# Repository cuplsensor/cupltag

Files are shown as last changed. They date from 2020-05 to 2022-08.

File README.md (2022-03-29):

# cuplTag
The project comprises hardware and firmware. 

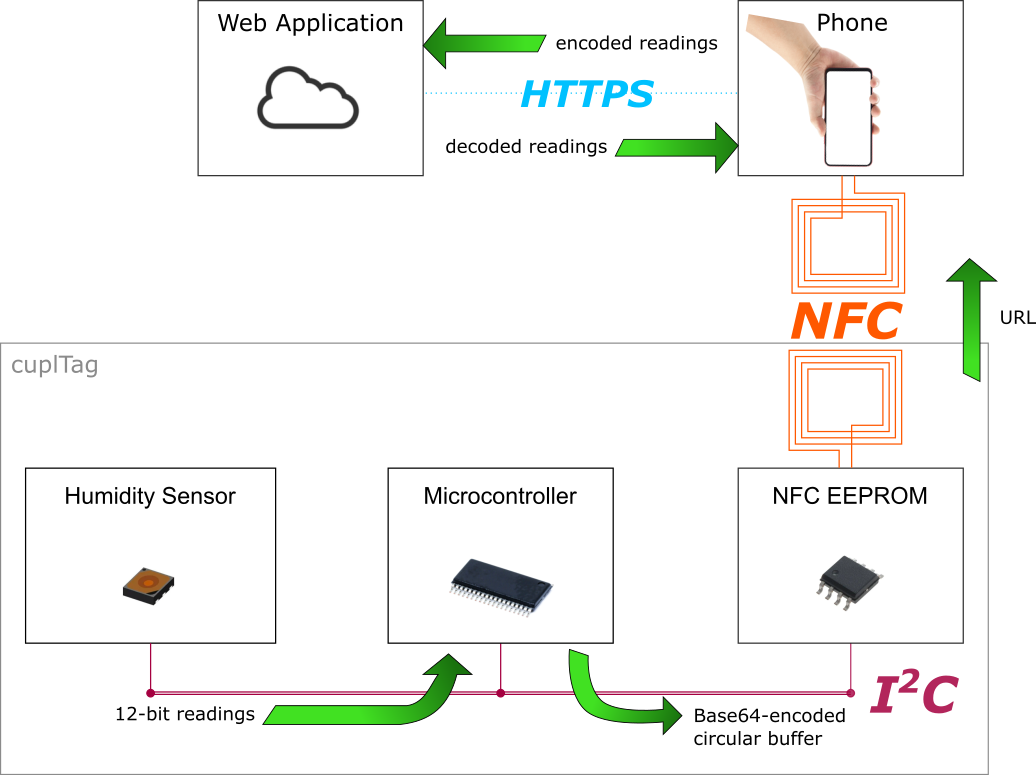
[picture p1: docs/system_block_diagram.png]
System block diagram


The firmware runs on a low power MSP430 microcontroller. It periodically reads temperature and humidity from an [HDC2022](https://www.ti.com/product/HDC2022) sensor. Readings are base-64 encoded and stored in a URL, which resides on an NFC EEPROM. 

When a phone is hovered over a cuplTag, the URL is read and a web browser opens ([demo](https://www.youtube.com/watch?v=ySxt_svazHo)). No app is required. The web application decodes, timestamps and displays readings to the user. 

## Key Features
- Average current consumption ~0.5uA. Runs for years on a CR1220 battery.
- Ease of use. No app to install on the Android / Apple phone.
- Data are automatically uploaded to the web.

[Buy one on Crowd Supply!](https://crowdsupply.com/cupl/cupltag)

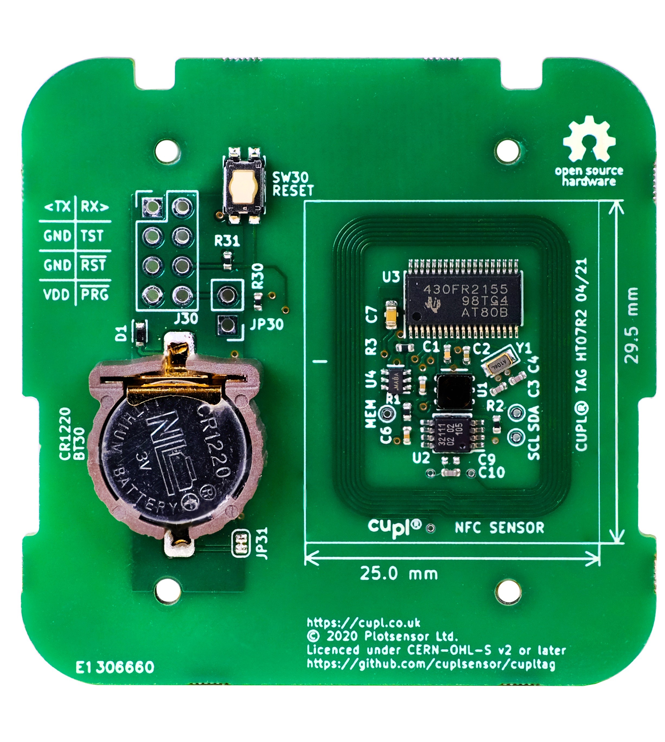
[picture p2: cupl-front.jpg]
Board photo


## Pinout

J30 is a 2.54mm pitch 2x4 way header.

| Pin | Name | Direction | Description | Note |
|-----|---|---|---|---|
| 1 | TX | Output | UART transmit | Transmit from MSP430 |
| 2 | RX | Input | UART receive | Receive to MSP430 |
| 3 | GND  | | GND | |
| 4 | TST  | Input | Spy-Bi-Wire Clock | Also TEST signal for BSL entry |
| 5 | GND  | | GND | |
| 6 | nRST | I/O | Spy-Bi-Wire Data  | Also active low RESET signal |
| 7 | VDD  | Input | Power in | +3V3 |
| 8 | nPRG | Input | Prog. Mode Enable | Active low |

## User Documentation 

### Guides

* [Getting Started](docs/firmware/gettingstarted.rst) by loading the project into Code Composer.
* [Programming](docs/firmware/programming/index.rst) the MSP430.
* [Configuration with UART (1 of 2)](docs/guides/configUARTpt1/index.md).
* [Configuration with UART (2 of 2)](https://github.com/cuplsensor/cuplfrontend/blob/master/docs/guides/configUARTpt2/index.md) [cuplfrontend].
* [Configuration with NFC](docs/guides/configNFC/index.md).

### Interface

* [Configuration Strings](docs/specs/configstrings.rst)  that can be written over the serial port or NFC.

## Code Documentation

[ReadTheDocs](https://cupl.readthedocs.io/projects/tag/en/latest/)

## Licence

### Firmware



### Hardware

[CERN Open Hardware Licence Version 2 - Strongly Reciprocal](https://ohwr.org/cern_ohl_s_v2.txt)

### Documentation



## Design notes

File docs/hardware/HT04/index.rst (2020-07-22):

HT04 Module
-------------

.. _HT04Pinout:

Pinout
*******

Diagram showing pinout of the HT04 module.

+-----+------+-----------+-------------------------+---------------------------------------+
| Pin | Name | Direction | Description             | Note                                  |
+=====+======+===========+=========================+=======================================+
| 1   | TX   | Output    | UART transmit           |                                       |
+-----+------+-----------+-------------------------+---------------------------------------+
| 2   | RX   | Input     | UART receive            | Also ADC input A6                     |
+-----+------+-----------+-------------------------+---------------------------------------+
| 3   | nPRG | Input     | Select programming mode | Active low                            |
+-----+------+-----------+-------------------------+---------------------------------------+
| 4   | TCK  | Input     | Spy-Bi-Wire Clock       | Also TEST signal for BSL entry        |
+-----+------+-----------+-------------------------+---------------------------------------+
| 5   | TDIO | I/O       | Spy-Bi-Wire Data        | Also nRESET signal                    |
+-----+------+-----------+-------------------------+---------------------------------------+
| 6   | GND  |           | GND                     |                                       |
+-----+------+-----------+-------------------------+---------------------------------------+
| 7   | VDD  | Input     | Power in                |                                       |
+-----+------+-----------+-------------------------+---------------------------------------+
| 8   | NC   |           | Not connected           |                                       |
+-----+------+-----------+-------------------------+---------------------------------------+
| 9   | SCL  | Output    | I2C clock               | Pulled-up to VMEM                     |
+-----+------+-----------+-------------------------+---------------------------------------+
| 10  | SDA  | Output    | I2C data                | Pulled-up to VMEM                     |
+-----+------+-----------+-------------------------+---------------------------------------+

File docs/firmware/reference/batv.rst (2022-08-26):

Battery Voltage 
~~~~~~~~~~~~~~~~~

.. doxygenfile:: batv.c

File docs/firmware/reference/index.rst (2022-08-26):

Reference
----------

.. toctree::
   :maxdepth: 2

   main
   hdc2021
   nt3h
   i2c
   stat
   confignfc
   comms_uart
   nvparams
   batv

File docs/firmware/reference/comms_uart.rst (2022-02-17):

Comms UART
~~~~~~~~~~~~

.. doxygenfile:: comms_uart.h

.. doxygenfile:: comms_uart.c

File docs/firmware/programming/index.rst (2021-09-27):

.. _Programming:

Programming
~~~~~~~~~~~~~

These instructions demonstrate how to program and debug the MSP430 on cuplTag.

Equipment
+++++++++++

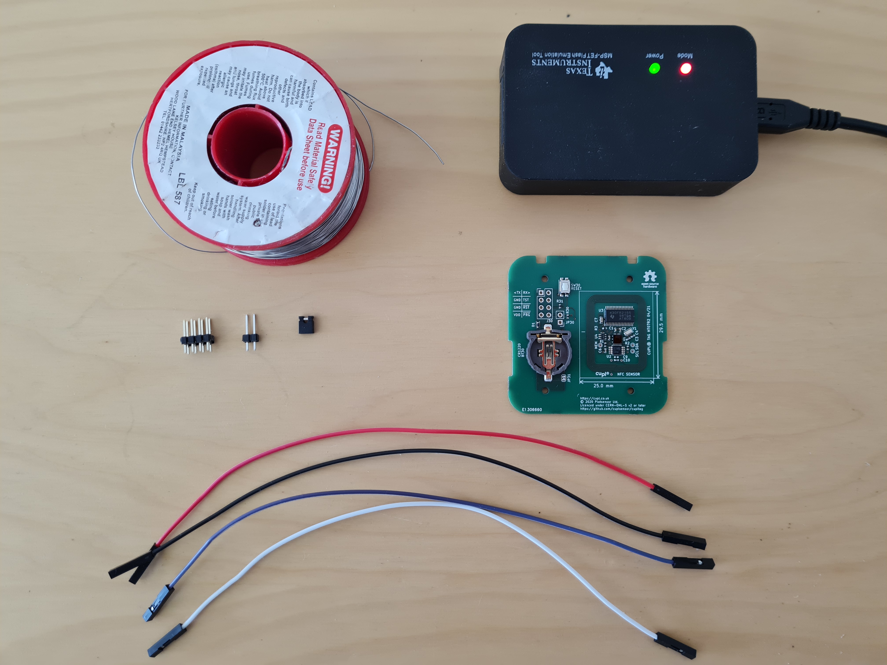
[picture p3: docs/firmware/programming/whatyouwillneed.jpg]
Items needed to program the MSP430


You will need: 

* An MSP-FET with a USB cable.
* A PC running Code Composer Studio.
* 4 coloured jumper wires.
* A 2x4 way 2.54mm pitch pin header.
* A 1x2 way 2.54mm pitch pin header.
* A 2 way jumper.
* Solder.
* A cuplTag PCBA (HT07), unscrewed from the enclosure, with no battery inserted.

Populate the Headers
+++++++++++++++++++++

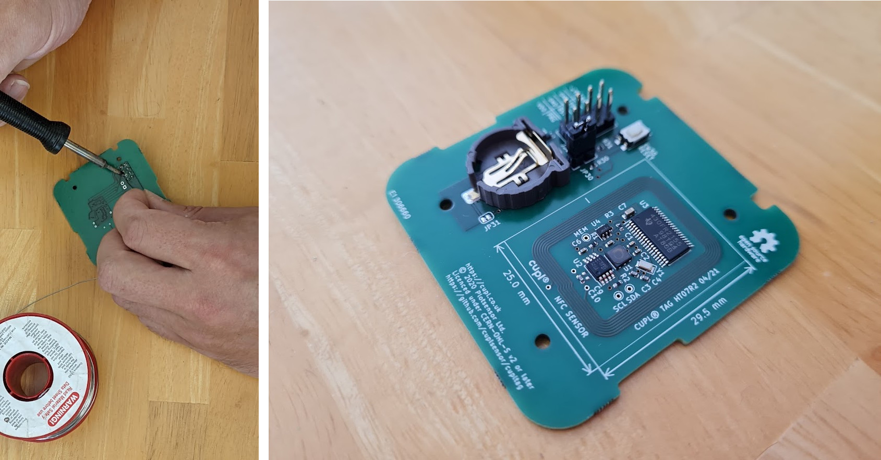
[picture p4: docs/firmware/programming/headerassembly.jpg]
Soldering headers onto HT07


First, solder the pin headers onto J30 and JP30 of HT07. Use the jumper to short JP30. 

Make Connections
+++++++++++++++++

In the diagram below we will make connection J2 instead of J1, because the HT07 has no battery inserted.

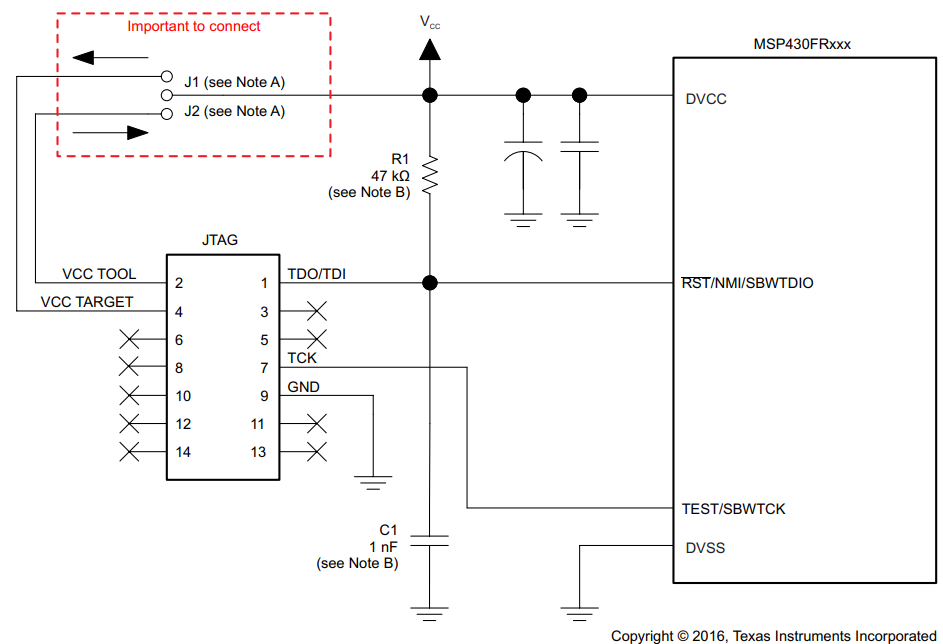
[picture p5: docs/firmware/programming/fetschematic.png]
MSP-FET Spy-Bi-Wire Schematic


Spy-Bi-Wire is used to progra . Connect it to the MSP-FET.

+---------+--------+--------------+-------------+--------------+-----------------+
| Name    | Colour | MSP-FET name | MSP-FET pin | HT07 J30 pin | HT07 J30 name   |
+---------+--------+--------------+-------------+--------------+-----------------+
| +3V3    | Red    | VCC_TOOL     | 2           | 7            | VDD             |
+---------+--------+--------------+-------------+--------------+-----------------+
| GND     | Black  | GND          | 9           | 3            | GND             |
+---------+--------+--------------+-------------+--------------+-----------------+
| SBWTDIO | White  | TDO/TDI      | 1           | 6            | nRST            |
+---------+--------+--------------+-------------+--------------+-----------------+
| SBWTCK  | Purple | TCK          | 7           | 4            | TST             |
+---------+--------+--------------+-------------+--------------+-----------------+

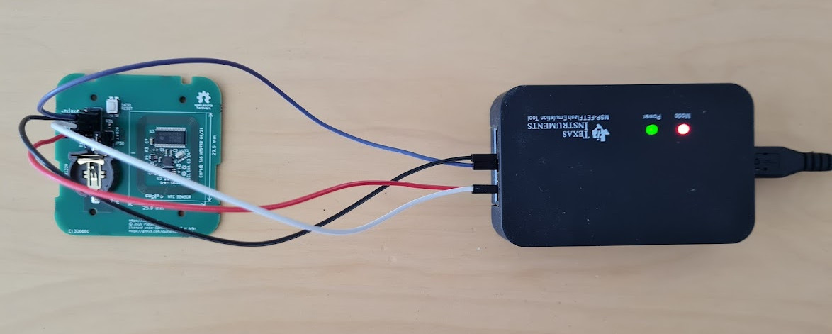
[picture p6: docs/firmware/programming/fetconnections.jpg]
Jumper wire connections on the MSP-FET


Program in CCS
+++++++++++++++++

#. Connect the MSP-FET to a PC with a USB cable. 
#. Open the Code Composer Studio cuplTag project `created earlier <GettingStarted>`.
#. Click on the Debug button. Wait for programming to complete.

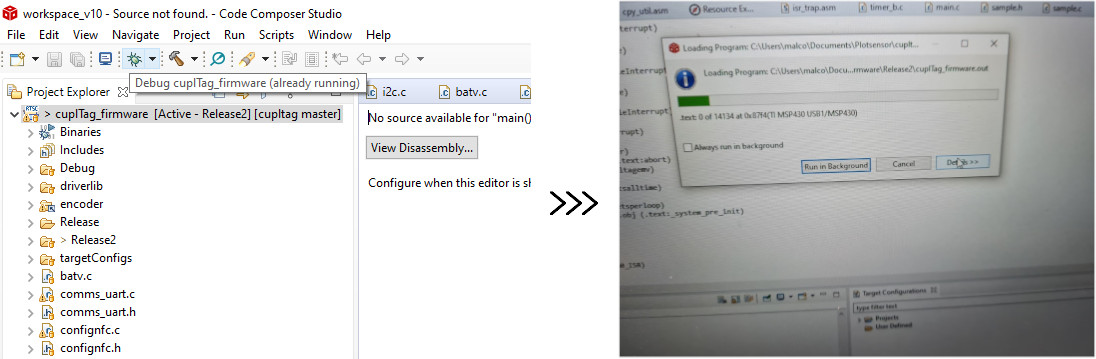
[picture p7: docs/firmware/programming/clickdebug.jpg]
Debug button in Code Composer Studio


Test
+++++

Test the program has loaded correctly by scanning HT07 with your phone. 

If JP30 is shorted, the MSP430 will boot into *programming mode*: The serial port is enabled and a status string is written to an NDEF text record on the tag.

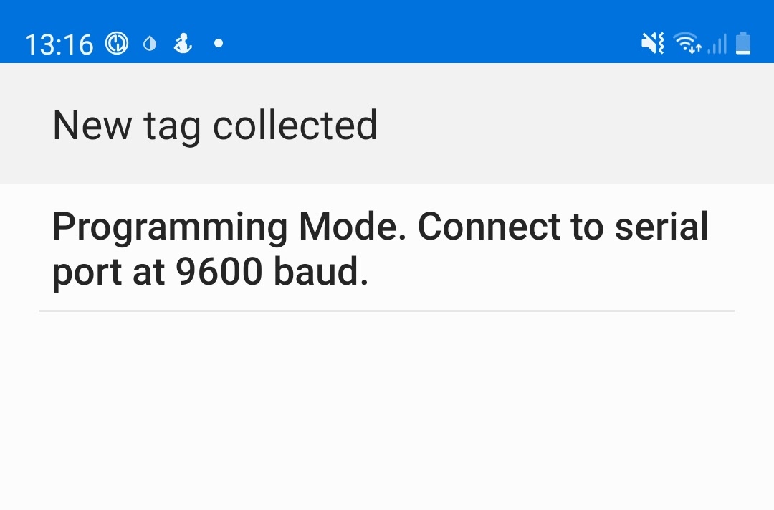
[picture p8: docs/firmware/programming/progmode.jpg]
Programming mode NDEF text record.


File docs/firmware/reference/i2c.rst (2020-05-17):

I2C
~~~~~~

.. doxygenfile:: i2c.h

.. doxygenfile:: i2c.c

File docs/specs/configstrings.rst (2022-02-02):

Configuration Strings
~~~~~~~~~~~~~~~~~~~~~~~

Base URL
*********

+------------------+------------------------------+
| Command ID       | b                            |
+------------------+------------------------------+
| Parameter Length | up to 64                     |
+------------------+------------------------------+
| Parameter value  | Any URL-safe string          |
+------------------+------------------------------+

Example 1: ``<b:localhost:5000>``

Example 2: ``<b:latest.f.cupl.uk>``

This URL will be opened by a phone that taps cuplTag. It should point to a `web application`_ that decodes the `cupl URL parameters`_. 

The scheme (e.g. HTTPS) must not be included.

The domain (e.g. latest.f.cupl.uk) is required. 

The port (e.g. 5000) is only required if it differs from 443 for HTTPS or 80 for HTTP.  

.. _web application: https://github.com/cuplsensor/cuplfrontend

.. _cupl URL parameters: https://cupl.readthedocs.io/projects/codec/en/latest/docs/specification/features.html#url-parameters

Serial
********

+------------------+---------------------+
| Command ID       | w                   |
+------------------+---------------------+
| Parameter Length | 8                   |
+------------------+---------------------+
| Parameter value  | Any URL-safe Base64 |
+------------------+---------------------+

Example: ``<w:KEG2lARW>``

Each cuplTag in a deployment must be uniquely identified by an 8 character serial string. This is written into a `dedicated URL parameter`_ on startup. 

The serial string is normally generated by the web application, when a new tag is defined. It can later be used to view data captured 
from a tag (e.g. https://latest.f.cupl.uk/tag/KEG2lARW).

.. _dedicated URL parameter: https://cupl.readthedocs.io/projects/codec/en/latest/docs/specification/features.html#CODEC_FEAT_38

HMAC Secret Key
*****************

+------------------+---------------------+
| Command ID       | s                   |
+------------------+---------------------+
| Parameter Length | 16                  |
+------------------+---------------------+
| Parameter value  | Any URL-safe Base64 |
+------------------+---------------------+

Example: ``<s:4EOBdBWTsjeFZTm3>``

The secret key is used to generate a `Hash-based Message Authentication Code`_, which is updated whenever a new sample is added to the URL. 

It must be randomly generated and unique to each cuplTag in a deployment. It is feasible for one tag (and the key therein) to be comprimised. 

The secret key will normally be generated by the web application, when a new tag is defined. It is shared between the application and the tag only. 

No data read from a tag will be stored by the web application without HMAC verification; the HMAC computed from the secret key must match that read from cuplTag.

.. _Hash-based Message Authentication Code: https://cupl.readthedocs.io/projects/codec/en/latest/docs/specification/features.html#CODEC_FEAT_24

Sample Interval in Minutes
****************************

+------------------+---------------------+
| Command ID       | t                   |
+------------------+---------------------+
| Parameter Length | 5 (max)             |
+------------------+---------------------+
| Parameter value  | Integer (16-bit)    |
+------------------+---------------------+

Example: ``<t:20>`` for a 20 minute interval.

This sets the time interval between samples in minutes. The minimum interval supported by the web application is 3 minutes. The maximum is 65535 minutes (6 weeks).

The time interval is base64 encoded and written into a `URL parameter` on startup. The web application uses this to timestamp all samples stored on the tag.

.. _URL parameter: https://cupl.readthedocs.io/projects/codec/en/latest/docs/specification/features.html#CODEC_FEAT_10

Disable HTTPS
**************

+------------------+---------------------------------------+
| Command ID       | h                                     |
+------------------+---------------------------------------+
| Parameter Length | 1                                     |
+------------------+---------------------------------------+
| Parameter value  | 0 (HTTPS), 1 (HTTP)                   |
+------------------+---------------------------------------+

Example: ``<h:1>`` to use HTTP (insecure) instead of HTTPS.

Disables HTTPS in the web application URL. This can be helpful during development, because there is no need to obtain an SSL certificate. Not encouraged for production. 

HTTPS and HTTP are the only 2 schemes supported by cuplTag for now.

Use HMAC
************

+------------------+---------------------------------------+
| Command ID       | i                                     |
+------------------+---------------------------------------+
| Parameter Length | 1                                     |
+------------------+---------------------------------------+
| Parameter value  | 0 (HMAC disabled), 1 (HMAC enabled)   |
+------------------+---------------------------------------+

Example ``<i:1>`` to use HMAC-MD5.

When HMAC is disabled, an MD5 checksum is calculated in its place. This means that the secret key is ignored and a decode will be successful providing that the checksums match. 

The feature was used during development, but it is not advised for production. MD5 may suffice for stateless web applications that do not store data from the tag. Standalone MD5 is deprecated as a checksum algorithm.

Minimum Battery Voltage (mV)
*****************************

+------------------+---------------------+
| Command ID       | u                   |
+------------------+---------------------+
| Parameter Length | 4                   |
+------------------+---------------------+
| Parameter value  | Integer (16-bit)    |
+------------------+---------------------+

Example: ``<u:2200>``

Sets the voltage below which the cuplTag does not operate.

Sample Format
**************

+------------------+----------------------------------------------+
| Command ID       | f                                            |
+------------------+----------------------------------------------+
| Parameter Length | 1                                            |
+------------------+----------------------------------------------+
| Parameter value  | 1 (Temperature + RH), 2 (Temperature only)   |
+------------------+----------------------------------------------+

Example 1: ``<f:1>`` for each sample to contain a temperature and relative humidity reading.

Example 2: ``<f:2>`` for each sample to contain a temperature reading only. This doubles the sample capacity.

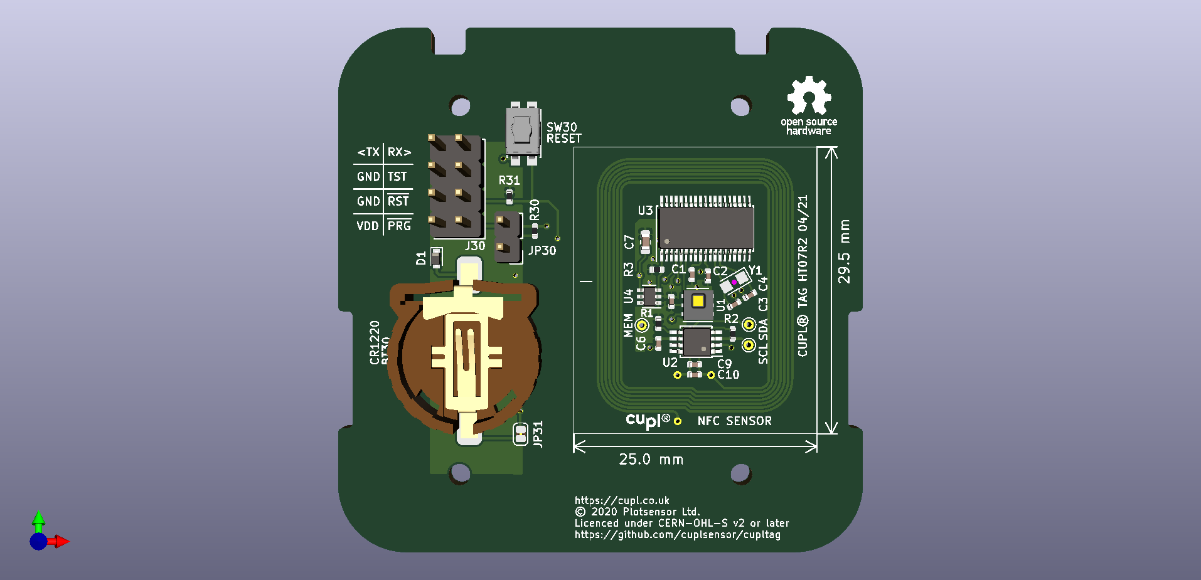
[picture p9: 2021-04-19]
hardware/HT07/HT07.png

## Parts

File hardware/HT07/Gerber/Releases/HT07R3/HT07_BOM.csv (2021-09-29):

Source: | C:\Users\malco\Documents\Plotsensor\cupltag\hardware\HT07\HT07.sch
Date: | 29/09/2021 13:37:43
Tool: | Eeschema (5.1.5)-3
Generator: | C:\Program Files\KiCad\bin\scripting\plugins/bom_csv_grouped_by_value.py
Component Count: | 32
Individual Components:
Item | Qty | Reference(s) | Value | LibPart | Footprint | Datasheet | ALT | COST@100 | FIT | MANF | MANF# | SUPPLIER | SUPPLIER#
 |  | AE1 | Antenna_Loop | device:Antenna_Loop | CUPL_FP:Class_6_NXP_7loop_150u | ~ |  |  | NF
 |  | BT30 | CR1220 | device:Battery_Cell | CUPL_FP:MPD_BC501SM_CR1220 | ~ |  |  |  | MPD | BC501SM | DIGIKEY | BC501SM-TRCT-ND
 |  | C1 | 1N | device:C | CUPL_FP:C_0402_1005Metric
 |  | C2 | 100N | device:C | CUPL_FP:C_0402_1005Metric |  |  |  |  | YAGEO | CC0402KRX7R7BB104 | FARNELL | 9402047
 |  | C3 | 22P | device:C | CUPL_FP:C_0402_1005Metric |  |  |  |  | AVX | 04025A220JAT2A | FARNELL | 1327634
 |  | C4 | 22P | device:C | CUPL_FP:C_0402_1005Metric |  |  |  |  | AVX | 04025A220JAT2A | FARNELL | 1327634
 |  | C6 | 100N | device:C | CUPL_FP:C_0402_1005Metric |  |  |  |  | YAGEO | CC0402KRX7R7BB104 | FARNELL | 9402047
 |  | C7 | 10U | device:C | CUPL_FP:C_0603_1608Metric |  |  | £0.115 |  | AVX | 06036D106MAT2A | FARNELL | 1833804
 |  | C8 | 100N | device:C | CUPL_FP:C_0402_1005Metric |  |  |  |  | YAGEO | CC0402KRX7R7BB104 | FARNELL | 9402047
 |  | C9 | 0P | device:C | CUPL_FP:C_0402_1005Metric |  |  |  | NF | AVX |  | FARNELL
 |  | C10 | 18P | device:C | CUPL_FP:C_0402_1005Metric |  |  |  |  | MURATA | 04025A180FAT2A | FARNELL | 2332495
 |  | D1 | D_Schottky | device:D_Schottky | CUPL_FP:D_SOD-523 | ~ |  |  |  | ROHM | RB520SM-40FHT2R | MOUSER | 755-RB520SM-40FHT2R
 |  | J30 | Conn_02x04_Odd_Even | Connector_Generic:Conn_02x04_Odd_Even | CUPL_FP:PinHeader_2x04_P2.54mm_Vertical | ~ |  |  | NF
 |  | JP30 | Jumper_2_Open | Jumper:Jumper_2_Open | CUPL_FP:PinHeader_1x02_P2.54mm_Vertical | ~ |  |  | NF
 |  | JP31 | SolderJumper_2_Bridged_small | Jumper:SolderJumper_2_Bridged | CUPL_FP:SolderJumper-2_Bridged_small | ~ |  |  | NF
 |  | LOGO1 | Logo_Open_Hardware_Small | Graphic:Logo_Open_Hardware_Small | CUPL_FP:OSHW-Logo_5.7x6mm_SilkScreen | ~
 |  | LOGO2 | CUPL | CUPL:CUPL | CUPL_FP:logo |  |  |  | NF
 |  | P1 | Conn_01x01_MountingPin | Mechanical:MountingHole | CUPL_FP:MountingHole_2.2mm_M2 | ~ |  |  | NF
 |  | P2 | Conn_01x01_MountingPin | Mechanical:MountingHole | CUPL_FP:MountingHole_2.2mm_M2 | ~ |  |  | NF
 |  | P3 | Conn_01x01_MountingPin | Mechanical:MountingHole | CUPL_FP:MountingHole_2.2mm_M2 | ~ |  |  | NF
 |  | P4 | Conn_01x01_MountingPin | Mechanical:MountingHole | CUPL_FP:MountingHole_2.2mm_M2 | ~ |  |  | NF
 |  | R1 | 10K | device:R | CUPL_FP:R_0402_1005Metric |  |  |  |  | VISHAY | CRCW040210K0FKED | FARNELL | 1469669
 |  | R2 | 10K | device:R | CUPL_FP:R_0402_1005Metric |  |  |  |  | VISHAY | CRCW040210K0FKED | FARNELL | 1469669
 |  | R3 | 100K | device:R | CUPL_FP:R_0402_1005Metric |  |  |  |  | BOURNS | CR0402-FX-1003GLF | MOUSER | 652-CR0402FX-1003GLF
 |  | R30 | 47K | device:R | CUPL_FP:R_0402_1005Metric |  |  |  |  | PANASONIC | ERJ2RKF4702X | FARNELL | 2302806
 |  | R31 | 47K | device:R | CUPL_FP:R_0402_1005Metric |  |  |  |  | PANASONIC | ERJ2RKF4702X | FARNELL | 2302806
 |  | SW30 | SW_Push | Switch:SW_Push | CUPL_FP:SW_SPST_EVQP2 | ~ |  |  |  | PANASONIC | EVQP2402W | FARNELL | 2860944
 |  | U1 | HDC2022DEPR | CUPL:HDC2021 | CUPL_FP:HDC2021 | https://www.ti.com/lit/ds/symlink/hdc2021.pdf |  |  |  | TEXAS | HDC2022DEPR | TEXAS | HDC2022DEPR
 |  | U2 | NT3H2111W0FTTJ | CUPL:NT3H2111 | CUPL_FP:TSSOP-8_3x3mm_P0.65mm | https://www.nxp.com/docs/en/data-sheet/NT3H2111_2211.pdf | ALT: NT3H2211W0FTTJ |  |  | NXP | NT3H2111W0FTTJ | FARNELL | 2663150
 |  | U3 | MSP430FR2155TDBT | CUPL:MSP430FR2155TDBT | CUPL_FP:TSSOP-38_4.4x9.7mm_P0.5mm | http://www.ti.com/lit/ds/symlink/msp430fr2155.pdf | ALT: MSP430FR2355TDBTR |  |  | TEXAS | MSP430FR2155TDBT | MOUSER | 595-MSP430FR2155TDBTR
 |  | U4 | SIP32431DR3-T1GE3 | CUPL:SIP32431DR3-T1GE3 | CUPL_FP:SOT-363_SC-70-6 | http://www.farnell.com/datasheets/2049671.pdf |  |  |  | VISHAY | SIP32431DR3-T1GE3 | FARNELL | 2361509
 |  | Y1 | 32K768 | CUPL:XTAL_32768HZ_3215 | CUPL_FP:Crystal_SMD_2012-2Pin_2.0x1.2mm_HandSoldering | http://www.farnell.com/datasheets/1912628.pdf |  | £0.36530 |  | EPSON | FC-12M 32.7680KD-A3 | DIGIKEY | SER3673CT-ND
Collated Components:
Item | Qty | Reference(s) | Value | LibPart | Footprint | Datasheet | ALT | COST@100 | FIT | MANF | MANF# | SUPPLIER | SUPPLIER#
1 | 1 | AE1 | Antenna_Loop | device:Antenna_Loop | CUPL_FP:Class_6_NXP_7loop_150u | ~ |  |  | NF
2 | 1 | BT30 | CR1220 | device:Battery_Cell | CUPL_FP:MPD_BC501SM_CR1220 | ~ |  |  |  | MPD | BC501SM | DIGIKEY | BC501SM-TRCT-ND
3 | 1 | C1 | 1N | device:C | CUPL_FP:C_0402_1005Metric
4 | 3 | C2, C6, C8 | 100N | device:C | CUPL_FP:C_0402_1005Metric |  |  |  |  | YAGEO | CC0402KRX7R7BB104 | FARNELL | 9402047
5 | 2 | C3, C4 | 22P | device:C | CUPL_FP:C_0402_1005Metric |  |  |  |  | AVX | 04025A220JAT2A | FARNELL | 1327634
6 | 1 | C7 | 10U | device:C | CUPL_FP:C_0603_1608Metric |  |  | £0.115 |  | AVX | 06036D106MAT2A | FARNELL | 1833804
7 | 1 | C9 | 0P | device:C | CUPL_FP:C_0402_1005Metric |  |  |  | NF | AVX |  | FARNELL
8 | 1 | C10 | 18P | device:C | CUPL_FP:C_0402_1005Metric |  |  |  |  | MURATA | 04025A180FAT2A | FARNELL | 2332495
9 | 1 | D1 | D_Schottky | device:D_Schottky | CUPL_FP:D_SOD-523 | ~ |  |  |  | ROHM | RB520SM-40FHT2R | MOUSER | 755-RB520SM-40FHT2R
10 | 1 | J30 | Conn_02x04_Odd_Even | Connector_Generic:Conn_02x04_Odd_Even | CUPL_FP:PinHeader_2x04_P2.54mm_Vertical | ~ |  |  | NF
11 | 1 | JP30 | Jumper_2_Open | Jumper:Jumper_2_Open | CUPL_FP:PinHeader_1x02_P2.54mm_Vertical | ~ |  |  | NF
12 | 1 | JP31 | SolderJumper_2_Bridged_small | Jumper:SolderJumper_2_Bridged | CUPL_FP:SolderJumper-2_Bridged_small | ~ |  |  | NF
13 | 1 | LOGO1 | Logo_Open_Hardware_Small | Graphic:Logo_Open_Hardware_Small | CUPL_FP:OSHW-Logo_5.7x6mm_SilkScreen | ~
14 | 1 | LOGO2 | CUPL | CUPL:CUPL | CUPL_FP:logo |  |  |  | NF
15 | 4 | P1, P2, P3, P4 | Conn_01x01_MountingPin | Mechanical:MountingHole | CUPL_FP:MountingHole_2.2mm_M2 | ~ |  |  | NF
16 | 2 | R1, R2 | 10K | device:R | CUPL_FP:R_0402_1005Metric |  |  |  |  | VISHAY | CRCW040210K0FKED | FARNELL | 1469669
17 | 1 | R3 | 100K | device:R | CUPL_FP:R_0402_1005Metric |  |  |  |  | BOURNS | CR0402-FX-1003GLF | MOUSER | 652-CR0402FX-1003GLF
18 | 2 | R30, R31 | 47K | device:R | CUPL_FP:R_0402_1005Metric |  |  |  |  | PANASONIC | ERJ2RKF4702X | FARNELL | 2302806
19 | 1 | SW30 | SW_Push | Switch:SW_Push | CUPL_FP:SW_SPST_EVQP2 | ~ |  |  |  | PANASONIC | EVQP2402W | FARNELL | 2860944
20 | 1 | U1 | HDC2022DEPR | CUPL:HDC2021 | CUPL_FP:HDC2021 | https://www.ti.com/lit/ds/symlink/hdc2021.pdf |  |  |  | TEXAS | HDC2022DEPR | TEXAS | HDC2022DEPR
21 | 1 | U2 | NT3H2111W0FTTJ | CUPL:NT3H2111 | CUPL_FP:TSSOP-8_3x3mm_P0.65mm | https://www.nxp.com/docs/en/data-sheet/NT3H2111_2211.pdf | ALT: NT3H2211W0FTTJ |  |  | NXP | NT3H2111W0FTTJ | FARNELL | 2663150
22 | 1 | U3 | MSP430FR2155TDBT | CUPL:MSP430FR2155TDBT | CUPL_FP:TSSOP-38_4.4x9.7mm_P0.5mm | http://www.ti.com/lit/ds/symlink/msp430fr2155.pdf | ALT: MSP430FR2355TDBTR |  |  | TEXAS | MSP430FR2155TDBT | MOUSER | 595-MSP430FR2155TDBTR
23 | 1 | U4 | SIP32431DR3-T1GE3 | CUPL:SIP32431DR3-T1GE3 | CUPL_FP:SOT-363_SC-70-6 | http://www.farnell.com/datasheets/2049671.pdf |  |  |  | VISHAY | SIP32431DR3-T1GE3 | FARNELL | 2361509
24 | 1 | Y1 | 32K768 | CUPL:XTAL_32768HZ_3215 | CUPL_FP:Crystal_SMD_2012-2Pin_2.0x1.2mm_HandSoldering | http://www.farnell.com/datasheets/1912628.pdf |  | £0.36530 |  | EPSON | FC-12M 32.7680KD-A3 | DIGIKEY | SER3673CT-ND

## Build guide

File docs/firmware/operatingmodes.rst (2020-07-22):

Operating Modes
-----------------

.. _NormalMode:

Primary
~~~~~~~~

The software progresses into the loop at the bottom of the :ref:`StateChart`:

* Programming mode is not entered because the nPRG pin is deasserted.
* Tag configuration is present according to :cpp:func:`init_configcheck`.
* No evidence of repeated resets has been found by :cpp:func:`init_errorcheck`.

In normal operation the tag is updated periodically with calls to cuplCodec. To conserve power the
MSP430 Real Time Clock (RTC) is set to generate interrupts at one minute intervals. The RTC
is clocked by the 32.768 kHz watch crystal. A majority of time is spent
waiting in standby (LPM3) for the next RTC interrupt. The VMEM domain that includes the NT3H2211 NFC tag
and the HDC2021 is powered off during this time.
Therefore cuplTag draws little more than 1.43uA; equal to the MSP430 consumption in LPM3 (`MSP430Datasheet`_).

Every Minute
*************

#. cuplTag wakes up from standby (LPM3).
#. Minute counter is incremented.
#. The VMEM domain is powered on.
#. A call is made to :cpp:func:`confignfc_check`. This checks if an NDEF text record
   (assumed to contain configuration data) is present on the tag. If so, a reset occurs.
#. A call is made to :cpp:func:`enc_setelapsed` in cuplCodec. The minuteselapsed field (CODEC_FEAT_26) of the cuplCodec URL
   is updated.
#. The VMEM domain is powered off.
#. cuplTag returns to LPM3.

At the Sample Interval (in minutes)
**************************************

#. cuplTag wakes up from standby (LPM3).
#. Minute counter is reset to 0.
#. The VMEM domain is powered on.
#. A call is made to :cpp:func:`confignfc_check`. This checks if an NDEF text record
   (assumed to contain configuration data) is present on the tag. If so, a reset occurs.
#. A sample is requested from the humidity sensor with :cpp:func:`hdc2010_startconv`.
#. The MSP430 waits in LPM3 until the DRDY line of this sensor is asserted.
#. The sample is read from the humidity sensor with :cpp:func:`hdc2010_read_temp`.
#. A call is made to :cpp:func:`enc_pushsample` in cuplCodec. The sample is written to the circular
   buffer inside the cuplCodec URL. The minuteselapsed field is reset to 0.
#. If the circular buffer has wrapped around to the start, then a call is made to :cpp:func:`nvparams_cresetsperloop`.
#. The VMEM domain is powered off.
#. cuplTag returns to LPM3.

Configuration file check
Block 1 of the NT3H2211 is read via I2C. If it contains a text record, then it is assumed
that a configuration file has been written. cuplTag resets to read the configuration file.

.. _ProgMode:

Secondary
~~~~~~~~~~~

The secondary operating mode is programming mode. The state :cpp:func:`init_progmode` is entered when the nPRG pin
is low after reset. A reset is triggered at power on or by a low pulse on the nRESET pin (see :ref:`HT04Pinout`).
The only way to leave programming mode is to trigger a reset. This is done either via the aforementioned means
or by sending the soft-reset command.

The serial port is active in this state and not in any other to save power. Connect with these settings:

+--------------+-------+
| Setting      | Value |
+==============+=======+
| Baudrate     | 9600  |
+--------------+-------+
| Parity       | None  |
+--------------+-------+
| Stop bit     | 1     |
+--------------+-------+
| Flow control | Off   |
+--------------+-------+

A simple command and response scheme is used. Basic commands have 3 characters:

+-----------+-----------------+---------------------------------------------+
| Character | Description     | Note                                        |
+===========+=================+=============================================+
|     <     | Start character |                                             |
+-----------+-----------------+---------------------------------------------+
|     z     | Command ID      | Any character in the range a-z, A-Z and 0-9 |
+-----------+-----------------+---------------------------------------------+
|     >     | End character   |                                             |
+-----------+-----------------+---------------------------------------------+

Configuration string commands add a parameter string:

+-----------+------------------+----------------------------------------+
| Character | Description      | Note                                   |
+===========+==================+========================================+
|     <     | Start character  |                                        |
+-----------+------------------+----------------------------------------+
|     b     | Command ID       | Any character in [a-z, A-Z, 0-9]       |
+-----------+------------------+----------------------------------------+
|     :     | Parameter prefix |                                        |
+-----------+------------------+----------------------------------------+
| ABcd1234  | Parameter string | Up to 64 characters in [a-z, A-Z, 0-9] |
+-----------+------------------+----------------------------------------+
|     >     | End character    |                                        |
+-----------+------------------+----------------------------------------+

Responses take a similar format to commands, starting with a '<' character and ending with a '>'.

A human-readable ASCII format was chosen because very little data is transacted.
It is useful to be able to send and receive commands through the terminal window without having to encode
and decode packets.

Basic Commands
***************

+---------+-----------+------------------------+--------------+---------------------------------------+
| Command | Name      | Response               | Example      | Description                           |
+=========+===========+========================+==============+=======================================+
| <x>     | Version   | <HWVER_FWVER_CODECVER> | <HT04_F2_C1> | Hardware, firmware and codec versions |
+---------+-----------+------------------------+--------------+---------------------------------------+
| <y>     | EnterBL   | None                   |              | Enter the MSP430 UART bootloader      |
+---------+-----------+------------------------+--------------+---------------------------------------+
| <z>     | SoftReset | None                   |              | Reset the MSP430                      |
+---------+-----------+------------------------+--------------+---------------------------------------+

Error Response
****************

The cuplTag firmware responds with '<e>' if it has failed to parse a command.

Configuration Commands
***********************

See configuration strings.

The :ref:`StateChart` shows a theoretical transition into an error state. This can only occur if the UART
state table is incomplete.

.. _MSP430Datasheet: https://www.ti.com/document-viewer/MSP430FR2155/datasheet/operating-modes-slasec45810#SLASEC45810

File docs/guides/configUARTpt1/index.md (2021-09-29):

# Configure cuplTag with UART (Part 1 of 2)

A programmed cuplTag must be configured. The [sampling interval](https://github.com/cuplsensor/cupltag/blob/master/docs/specs/configstrings.rst#sample-interval-in-minutes) and other parameters are stored in non-volatile [Information Memory](https://www.ti.com/document-viewer/MSP430FR2155/datasheet/memory-organization-slasec43899#SLASEC43899). At startup, the MSP430 writes an error message to the [NT3H2111](https://www.nxp.com/docs/en/data-sheet/NT3H2111_2211.pdf) if configuration is incomplete.

## Equipment

You will need:

* A cuplTag PCBA (HT07). This must be [programmed](https://github.com/cuplsensor/cupltag/blob/master/docs/firmware/programming/index.rst#programming), with headers J30 and JP30 populated.
* 4 coloured jumper wires.
* A USB-to-serial converter. An [MSP-FET](https://www.ti.com/tool/MSP-FET) is used in this guide, but anything will do.
* A PC running [TeraTerm](https://ttssh2.osdn.jp/index.html.en).

## Make Connections

### JP30

Place the shorting jumper on HT07 JP30. This will cause *Programming Mode* to be invoked (and the serial port enabled) on startup.

### J30

| Name | Colour | MSP-FET name | MSP-FET pin | J30 pin | J30 name |
| --- | --- | --- | --- | --- | --- |
| +3V3*  | Red | VCC_TOOL | 2 | 7 | VDD |
| GND | Black  | GND | 9 | 3 | GND |
| TX | Yellow | UART_TXD | 12 | 1 | <TX |
| RX | Green  | UART_RXD | 14 | 2 | RX> |

\*If the HT07 has a coin cell inserted, only GND, TX and RX are required.

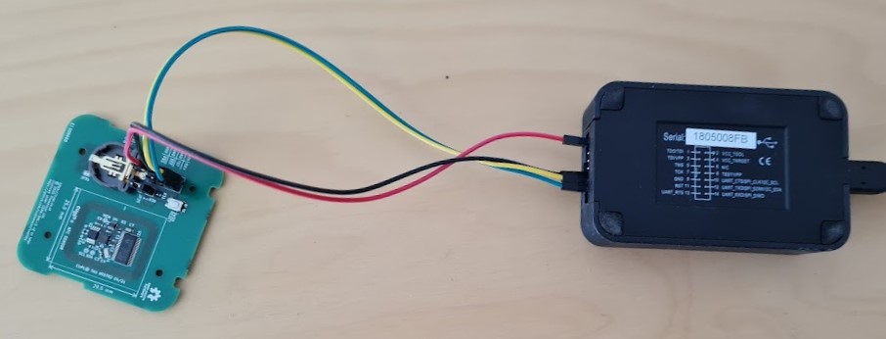
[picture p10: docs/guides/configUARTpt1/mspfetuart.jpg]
MSP-FET connected to a cuplTag via UART


## Test with TeraTerm

1. Connect the MSP-FET to a USB port on your PC.
2. Open TeraTerm.
3. Click Setup -> Serial Port...
4. **Port** the Application UART port for your MSP-FET. This can be found in device manager.

      MSP Application UART in Device Manager
   
5. **Speed** 9600 baud
6. **Data** 8 bit.
7. **Parity** None.
8. **Stop bits** 1 bit.
9. **Flow control** None.
10. Click OK.
11. Press the RESET button on HT07. You will see `<boot>`.
    
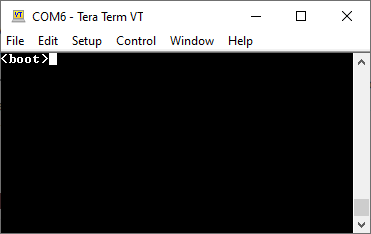
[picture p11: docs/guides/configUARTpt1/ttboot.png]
boot string in TeraTerm
      

12. Send `<x>`. The version string will be printed.
      
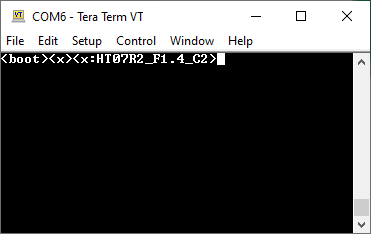
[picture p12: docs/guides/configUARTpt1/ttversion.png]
Version string in Teraterm
      

## Part 2
Read [Part 2](https://github.com/cuplsensor/cuplfrontend/blob/master/docs/guides/configUARTpt2/index.md)

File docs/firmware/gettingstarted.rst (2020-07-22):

Getting Started
----------------

Prerequisites
~~~~~~~~~~~~~~~
* MSP-FET debugger (`TI <https://www.ti.com/tool/MSP-FET>`_).
* GitHub Desktop (`download <https://desktop.github.com/>`_) or your choice of Git software.

Fork and Clone cupl Tag
~~~~~~~~~~~~~~~~~~~~~~~~~~~

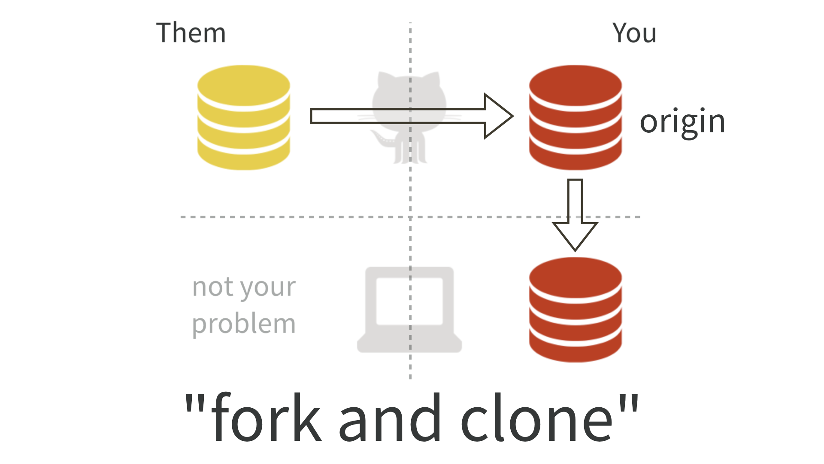
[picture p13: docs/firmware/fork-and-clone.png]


Visit the cupl Tag repository on (`GitHub <https://github.com/cuplsensor/cupltag>`_). Click the
fork button in the top right.

Clone the forked repository to your computer by clicking the green Clone or Download button. See
`<https://guides.github.com/activities/forking/>`_ for more details.

Open the Code Composer Project
~~~~~~~~~~~~~~~~~~~~~~~~~~~~~~~~

#. `Download <https://software-dl.ti.com/ccs/esd/documents/ccs_downloads.html>`_ and install Code Composer Studio 10 (CCS).
#. Open CCS. Launch the workspace of your choice.
#. Click File -> Open Projects from File System...
#. In Import Source, select the folder containing the clone of cupl Tag.

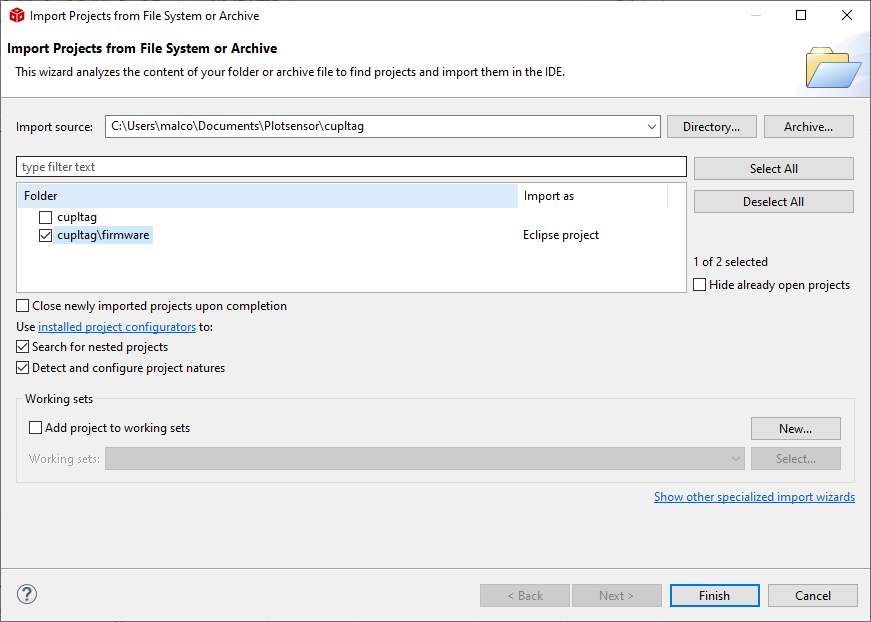
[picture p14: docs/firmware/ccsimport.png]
    

#. Ensure that cupltag\\firmware is **checked**. Every other folder should be unchecked.
#. Click Finish.
#. The project is now open.

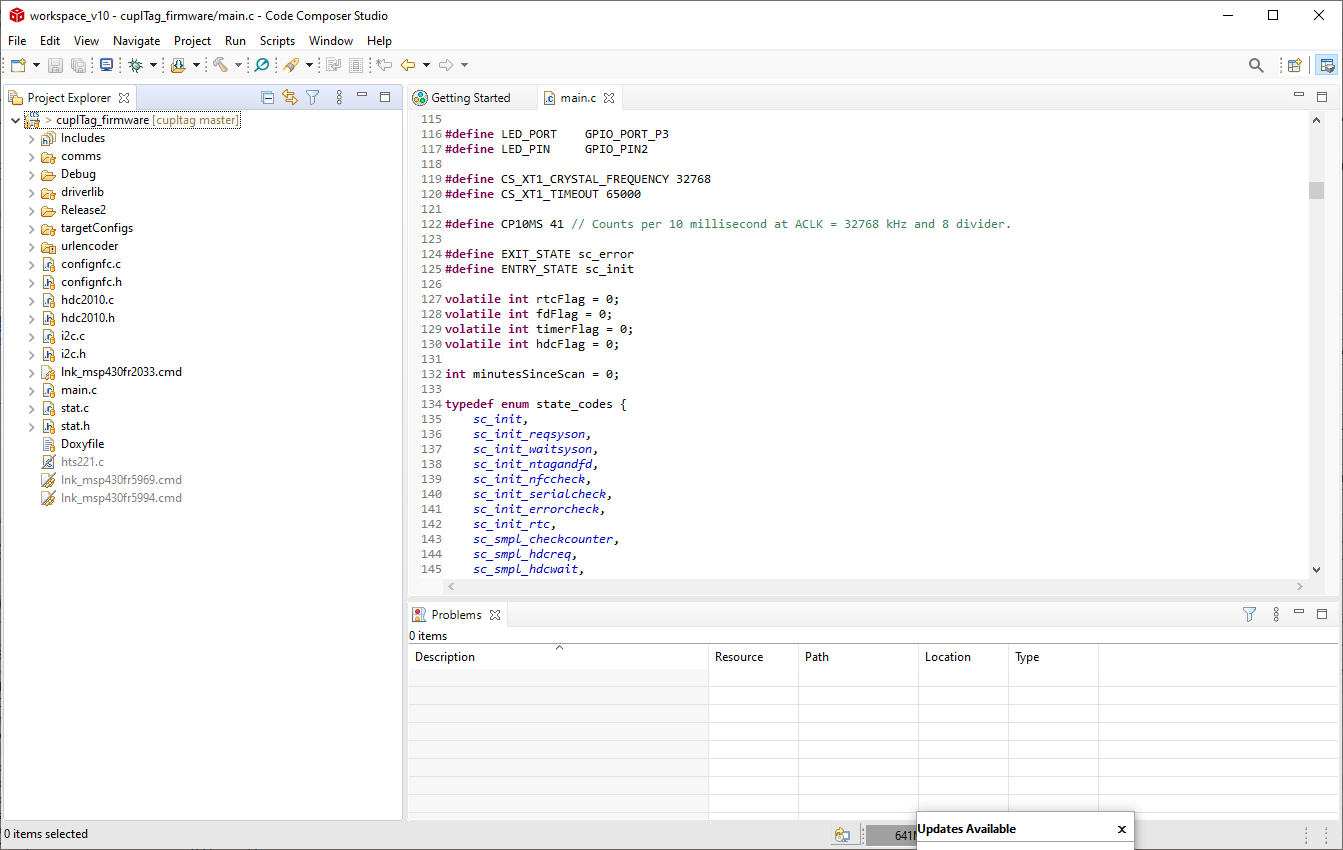
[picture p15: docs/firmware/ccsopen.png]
    

Add Reference to cuplCodec
~~~~~~~~~~~~~~~~~~~~~~~~~~~~~~~~~

The cuplTag firmware depends on C files from cuplCodec.

#. Fork the cuplCodec repository on (`GitHub <https://github.com/cuplsensor/cuplcodec>`_).
#. Clone this into a folder on your computer.
#. In CCS, right click the cuplTag_firmware project.
#. Select Properties from the context menu.
#. In the Properties window, expand Resource on the left hand panel and select Linked Resources.

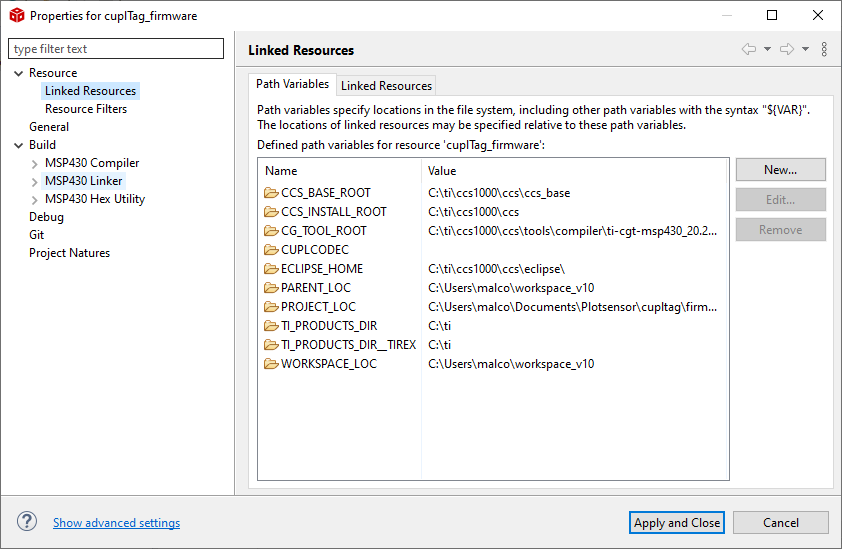
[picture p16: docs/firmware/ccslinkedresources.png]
    

#. Double click the CUPLCODEC path variable. The Edit Variable window will appear.

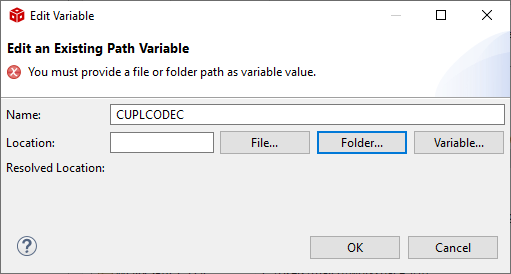
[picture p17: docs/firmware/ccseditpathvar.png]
    

#. Click the Folder... button. Select the Codec clone folder from step 2.
#. Click Apply and Close.
#. The cuplcodec_encoder project folder will now contain references to files inside cupl Codec.

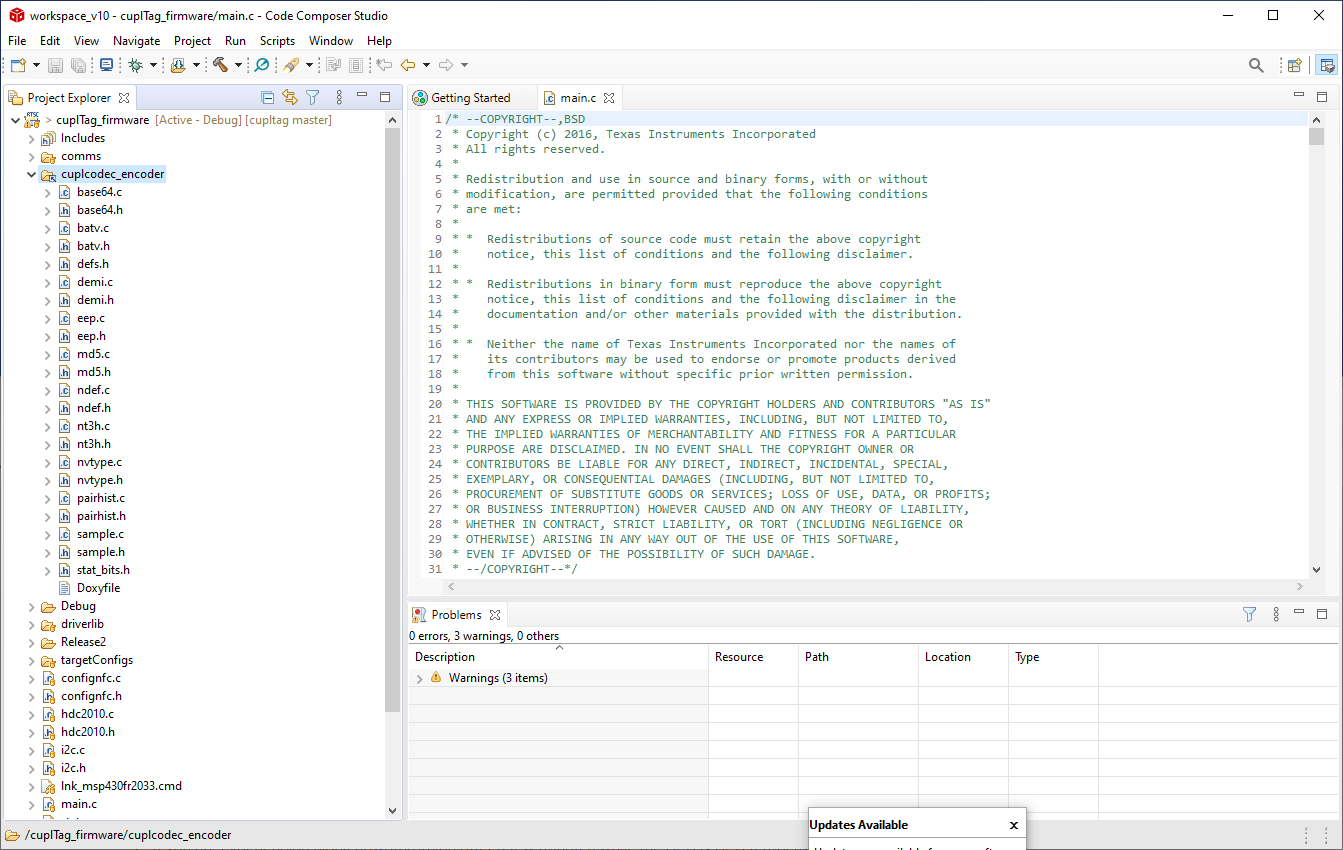
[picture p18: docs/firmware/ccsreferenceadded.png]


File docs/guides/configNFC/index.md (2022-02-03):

# Configure cuplTag with NFC

[Configuration strings](https://github.com/cuplsensor/cupltag/blob/master/docs/specs/configstrings.rst) can be written to the the tag inside an NDEF text record. 

The tag detects the text record and will reset within one minute. Strings are read and parsed on startup.

NFC configuration allows end users to make changes in the field. Most often this will be to the sample type or interval. In rare cases, the web application will go down and the base URL will need to be modified. If the tag is conformally coated, it is difficult to make a [wired connection](https://github.com/cuplsensor/cupltag/blob/master/docs/guides/configUARTpt1/index.md) after production. 

:fire: Do you use [**Chrome for Android V97+**](https://caniuse.com/webnfc)? Watch these [instructions](https://www.youtube.com/watch?v=UxrxsgZ2lA8) for an app-free alternative.

1. Download the NFC Tools app from [Google Play](https://play.google.com/store/apps/details?id=com.wakdev.wdnfc&hl=en_GB&gl=US) or the [iPhone](https://apps.apple.com/us/app/nfc-tools/id1252962749) App Store.

2. Select the **WRITE** tab. 

   

3. Select **Add a Record**.

4. Select **Text**.
5. Enter one or more configuration strings. Do not use spaces, carriage returns or separators between strings. 
   
   *The example below sets the time interval between samples to 5 minutes.*
   
   
   
6. Press **OK**.

7. The next screen shows the new NDEF text record inside an NDEF message. 
   
   
8. Select **Write**.

   

9. Tap to write the NDEF message.

   

10. Wait for one minute or press the RESET button.
      
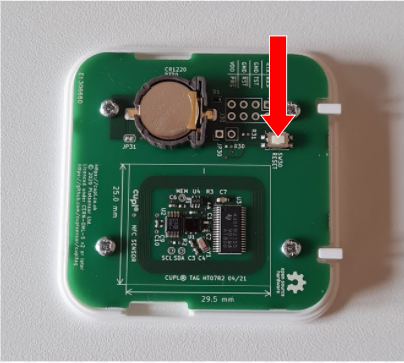
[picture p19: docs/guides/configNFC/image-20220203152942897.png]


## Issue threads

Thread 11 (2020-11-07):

Tag error with no q argument when plugged into FET

malcolmmackay, 2020-11-07:
Reset button must be pressed after plugging in for normal operation.

Closed 2022-03-29.

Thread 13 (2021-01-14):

Remove 47K pull up resistor from the tag itself.

malcolmmackay, 2021-01-14:
The 47K pull up should be external. This allows the user to add an RC network on the RST line, and optionally one with a 2K2 series resistor that still allows for Spy-Bi-Wire connections. https://e2e.ti.com/support/microcontrollers/msp430/f/166/t/631751?MSP430FR4133-TI-s-version-of-RESET-circuit

Closed 2022-03-29.

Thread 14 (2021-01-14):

Remove 47K resistor

malcolmmackay, 2021-01-14:
The 47K pull up should be external. This allows the user to add an RC network on the RST line, and optionally one with a 2K2 series resistor that still allows for Spy-Bi-Wire connections. https://e2e.ti.com/support/microcontrollers/msp430/f/166/t/631751?MSP430FR4133-TI-s-version-of-RESET-circuit

Closed 2022-03-29.

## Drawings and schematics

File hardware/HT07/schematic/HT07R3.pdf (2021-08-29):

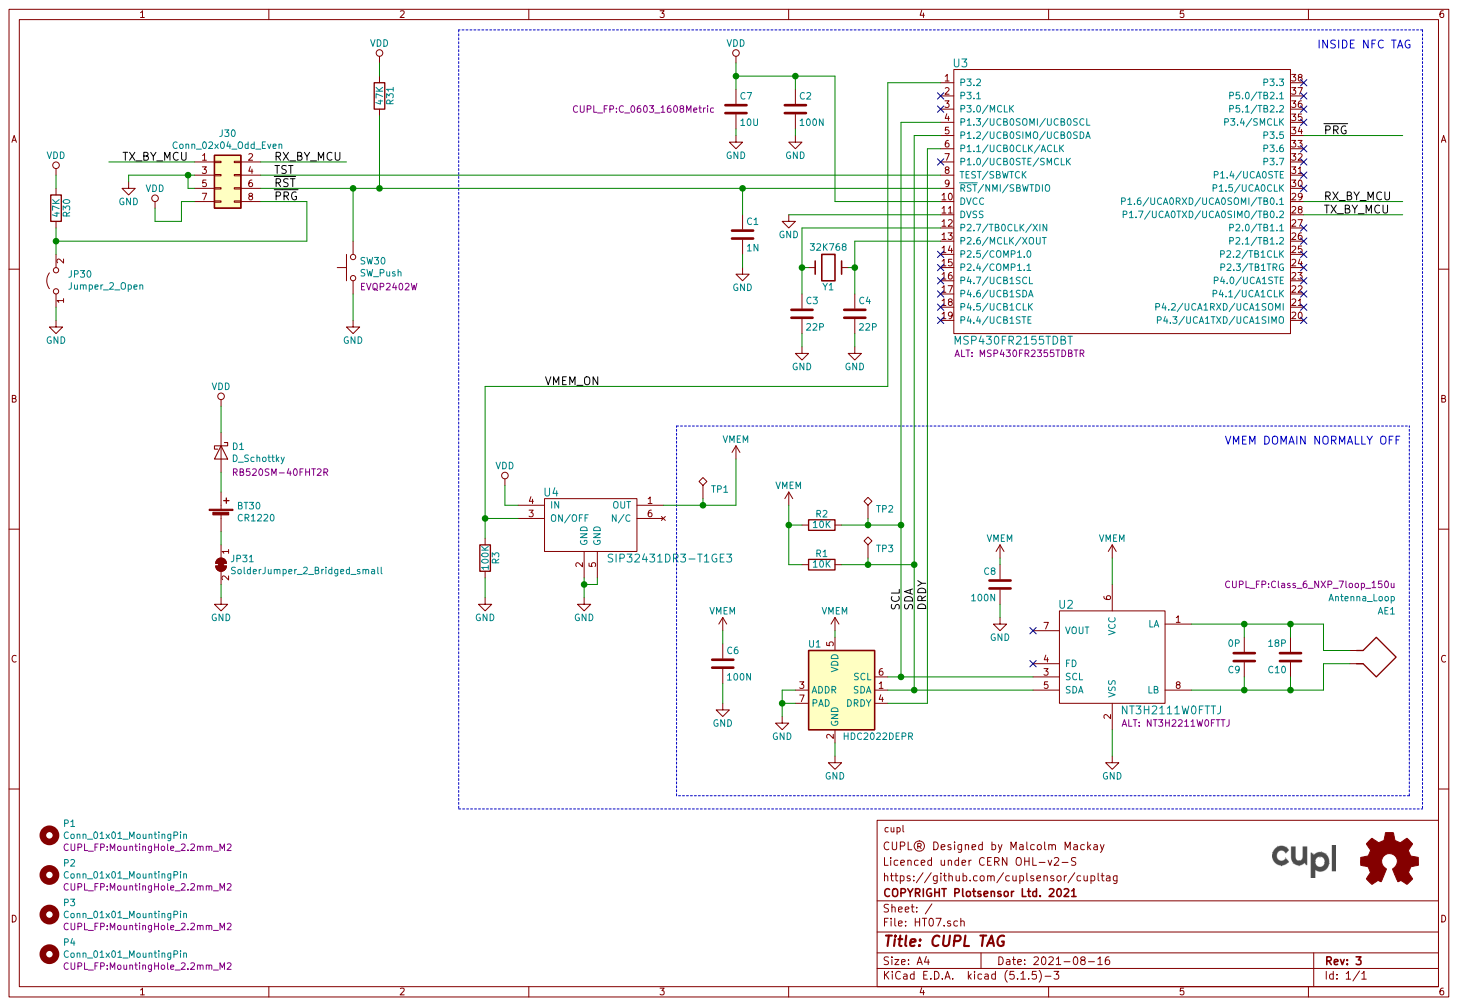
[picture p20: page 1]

TST
RST

VMEM DOMAIN NORMALLY OFF

2 SCL 3 FD 4 SDA 5 VCC

https://github.com/cuplsensor/cupltag
File: HT07.sch Sheet: / COPYRIGHT Plotsensor Ltd. 2021

Id: 1/1 Title: CUPL TAG

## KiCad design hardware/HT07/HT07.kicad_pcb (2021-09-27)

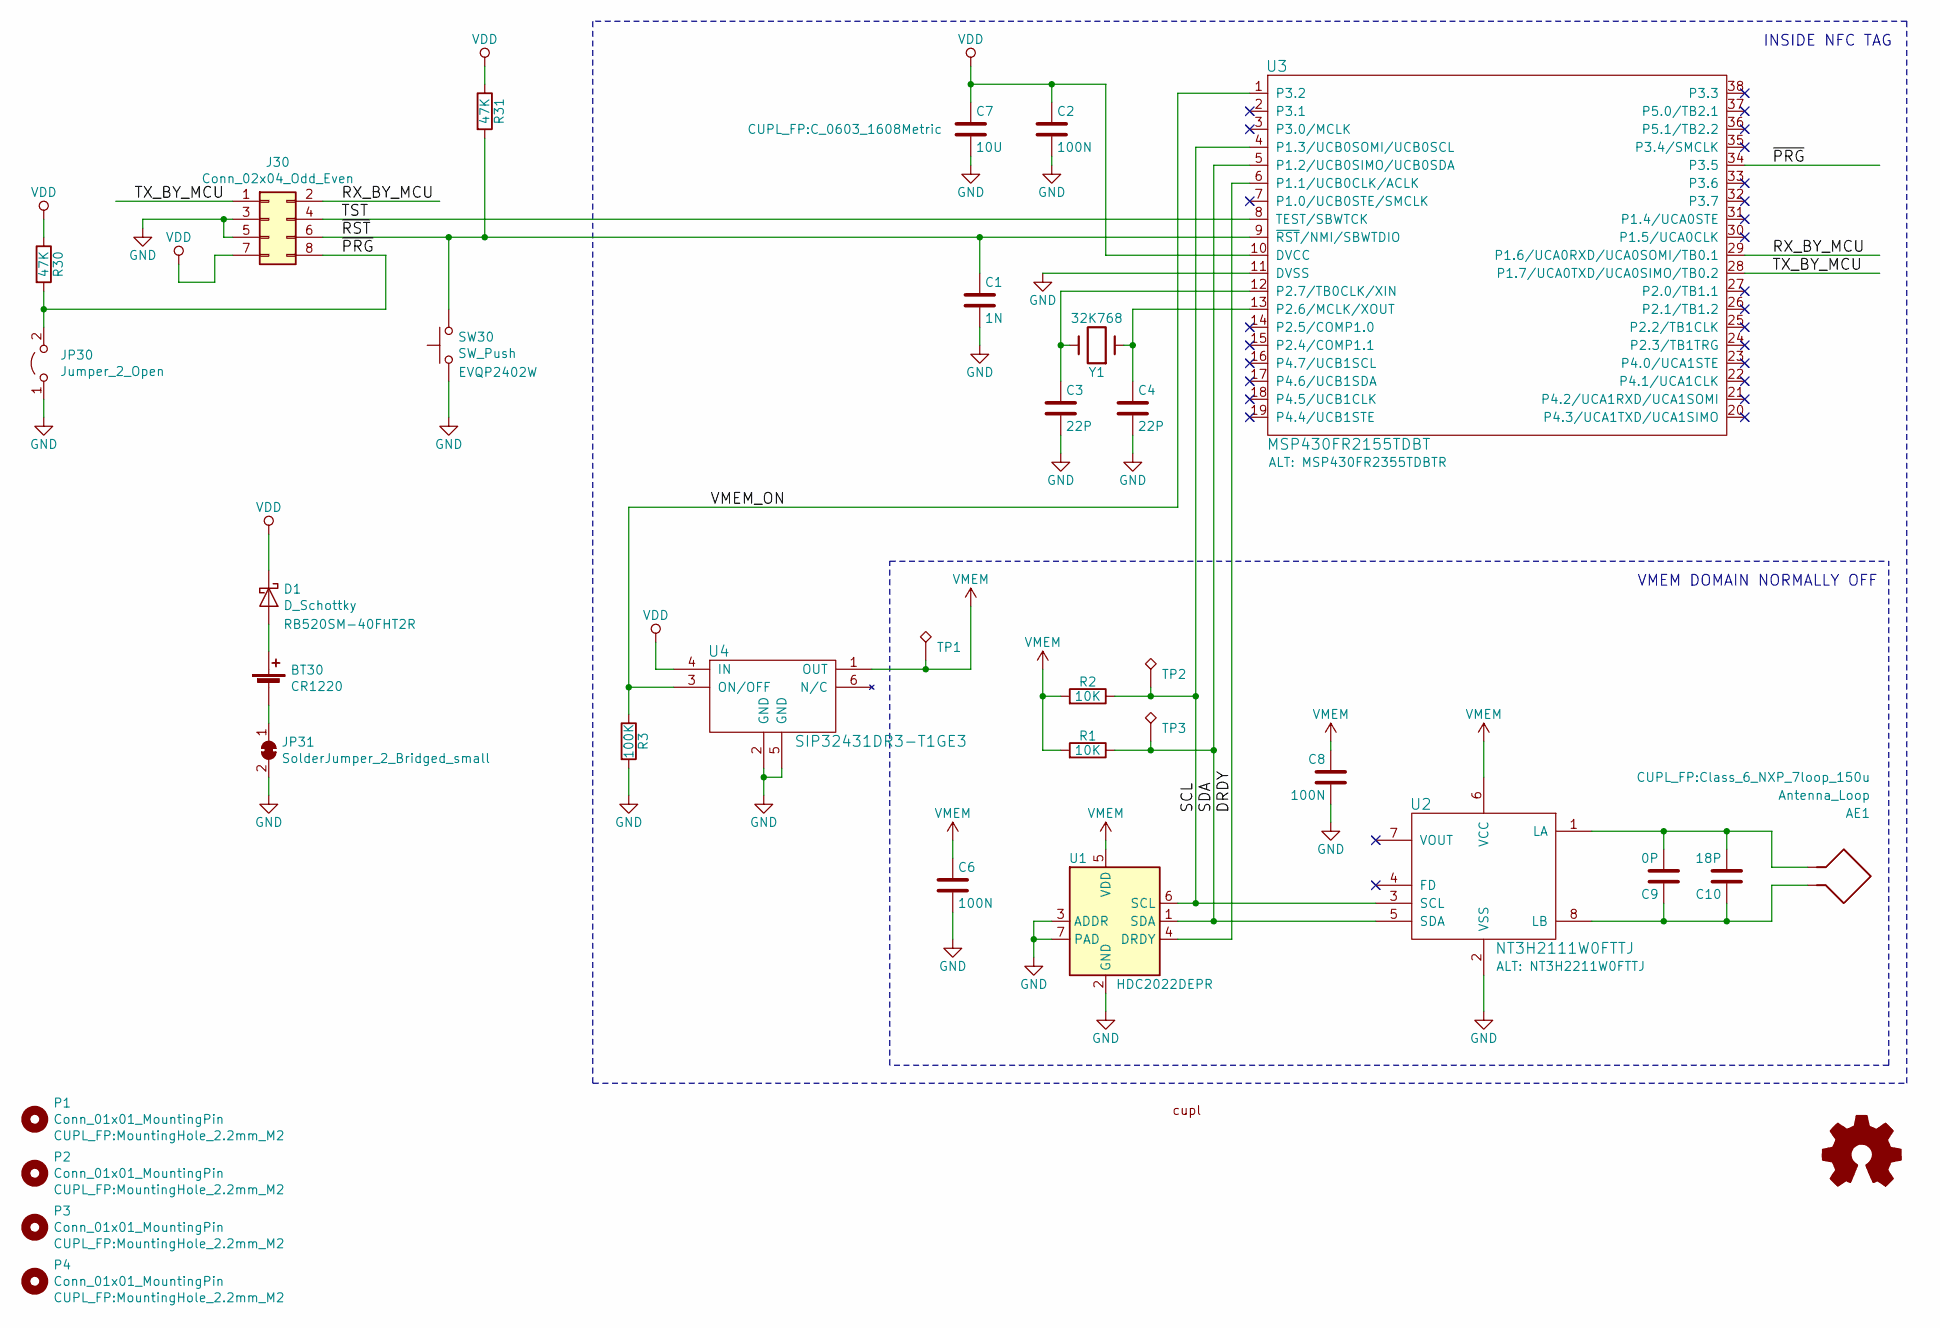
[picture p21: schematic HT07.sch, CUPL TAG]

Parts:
AE1: Antenna_Loop; Class_6_NXP_7loop_150u
BT30: CR1220; MPD_BC501SM_CR1220
C1: 1N; C_0402_1005Metric
C2, C6, C8: 100N; C_0402_1005Metric
C3, C4: 22P; C_0402_1005Metric
C7: 10U; C_0603_1608Metric
C9: 0P; C_0402_1005Metric
C10: 18P; C_0402_1005Metric
D1: D_Schottky; D_SOD-523
J30: Conn_02x04_Odd_Even; PinHeader_2x04_P2.54mm_Vertical
JP30: Jumper_2_Open; PinHeader_1x02_P2.54mm_Vertical
JP31: SolderJumper_2_Bridged_small; SolderJumper-2_Bridged_small
LOGO1: Logo_Open_Hardware_Small; OSHW-Logo_5.7x6mm_SilkScreen
LOGO2: CUPL; logo
P1, P2, P3, P4: Conn_01x01_MountingPin; MountingHole_2.2mm_M2
R1, R2: 10K; R_0402_1005Metric
R3: 100K; R_0402_1005Metric
R30, R31: 47K; R_0402_1005Metric
SW30: SW_Push; SW_SPST_EVQP2
TP1: MEM; TestPoint_THTPad_D1.0mm_Drill0.5mm
TP2: SCL; TestPoint_THTPad_D1.0mm_Drill0.5mm
TP3: SDA; TestPoint_THTPad_D1.0mm_Drill0.5mm
U1: HDC2022DEPR; HDC2021
U2: NT3H2111W0FTTJ; TSSOP-8_3x3mm_P0.65mm
U3: MSP430FR2155TDBT; TSSOP-38_4.4x9.7mm_P0.5mm
U4: SIP32431DR3-T1GE3; SOT-363_SC-70-6
Y1: 32K768; Crystal_SMD_2012-2Pin_2.0x1.2mm_HandSoldering

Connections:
/DRDY: U1.4 (DRDY), U3.6 (P1.1/UCB0CLK/ACLK)
/RX_BY_MCU: J30.2, U3.29 (P1.6/UCA0RXD/UCA0SOMI/TB0.1)
/SCL: R2.1, TP2.1, U1.6 (SCL), U2.3 (SCL), U3.4 (P1.3/UCB0SOMI/UCB0SCL)
/SDA: R1.1, TP3.1, U1.1 (SDA), U2.5 (SDA), U3.5 (P1.2/UCB0SIMO/UCB0SDA)
/TST: J30.4, U3.8 (TEST/SBWTCK)
/TX_BY_MCU: J30.1, U3.28 (P1.7/UCA0TXD/UCA0SIMO/TB0.2)
/VMEM_ON: R3.1, U3.1 (P3.2), U4.3 (ON/OFF)
/~PRG~: J30.8, JP30.2 (B), R30.2, U3.34 (P3.5)
/~RST~: C1.1, J30.6, R31.2, SW30.2, U3.9 (~RST~/NMI/SBWTDIO)
GND: C1.2, C2.2, C3.2, C4.2, C6.2, C7.2, C8.2, J30.3, J30.5, JP30.1 (A), JP31.2 (B), R3.2, SW30.1, U1.2 (GND), U1.3 (ADDR), U1.7 (PAD), U2.2 (VSS), U3.11 (DVSS), U4.2 (GND), U4.5 (GND)
unnamed: AE1.1, C9.2, C10.2, U2.1 (LA)
unnamed: AE1.2, C9.1, C10.1, U2.8 (LB)
unnamed: BT30.1 (+), D1.2 (A)
unnamed: BT30.2 (-), JP31.1 (A)
unnamed: C3.1, U3.12 (P2.7/TB0CLK/XIN), Y1.2
unnamed: C4.1, U3.13 (P2.6/MCLK/XOUT), Y1.1
VDD: C2.1, C7.1, D1.1 (K), J30.7, R30.1, R31.1, U3.10 (DVCC), U4.4 (IN)
VMEM: C6.1, C8.1, R1.2, R2.2, TP1.1, U1.5 (VDD), U2.6 (VCC), U4.1 (OUT)

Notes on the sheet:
VMEM DOMAIN NORMALLY OFF
INSIDE NFC TAG

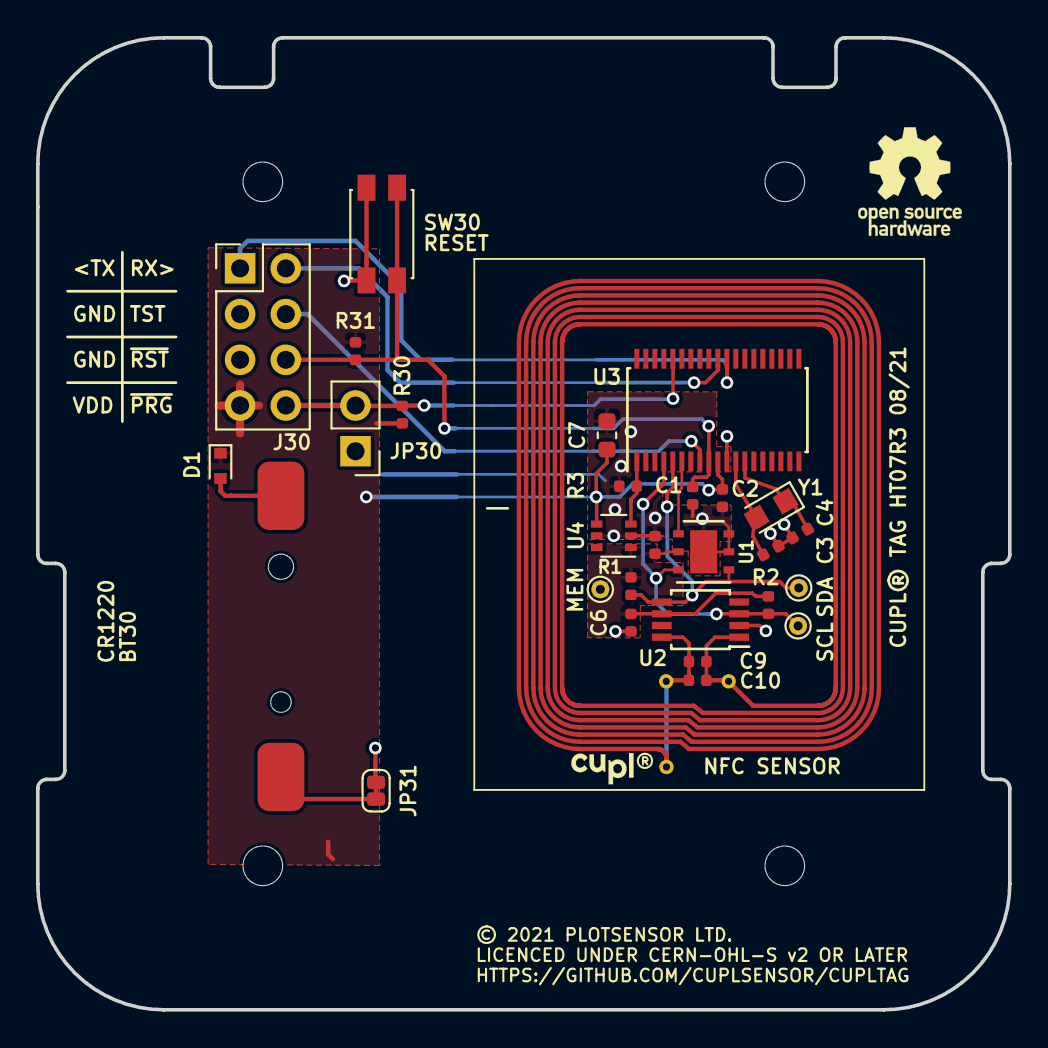
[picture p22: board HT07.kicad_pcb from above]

Board: 2 copper layers, 54.0 x 54.0 mm, 35 parts (0 on the bottom side), 18 nets.

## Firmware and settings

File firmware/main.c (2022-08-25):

/*  This MSP430FR2155 program collects data from an HDC2010 sensor and
 *  passes it to the encoder part of cuplcodec.
 *
 *  https://github.com/cuplsensor/cupltag
 *
 *  Original Author: Malcolm Mackay
 *  Email: malcolm@plotsensor.com
 *
 *  Copyright (C) 2021. Plotsensor Ltd.
 *
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
 *  You should have received a copy of the GNU General Public License
 *  along with this program.  If not, see <https://www.gnu.org/licenses/>.
 */

/**
 * @file main.c
 * @author Malcolm Mackay
 *
 * @brief Top-level Finite State Machine for controlling the MSP430 and cuplTag as a whole.
 *
 * A Finite State Machine is defined in this file and run from main(). This has several features.
 *
 * It makes calls to drivers for communicating with the HDC2022 humidity sensor and the NT3H2111 NFC EEPROM.
 *
 * It controls entry into the 'programming mode' sub state machine, where configuration strings can be written
 * using a serial port.
 *
 * It reads configuration strings from the NFC EEPROM if any are present.
 *
 * It collects samples from an HDC2022 at a fixed time interval and passes these to the cuplcodec encoder.
 *
 */

#include "driverlib.h"
#include "hdc2021.h"
#include "sample.h"
#include "comms_uart.h"
#include "confignfc.h"
#include "nt3h.h"
#include "stat.h"
#include "defs.h"
#include "eep.h"
#include "batv.h"
#include <stdlib.h>


#define CS_SMCLK_DESIRED_FREQUENCY_IN_KHZ   1000       /*!< Target frequency for SMCLK in kHz. */

#define CS_XT1_CRYSTAL_FREQUENCY            32768       /*!< Resonant frequency of the XT1 crystal in kHz. */
#define CS_XT1_TIMEOUT                      65000       /*!< Timeout for XT1 to stabilise at the resonant frequency in SMCLK cycles. */

#define CP10MS                                  41      /*!< ACLK Cycles Per 10 MilliSeconds. Assumes ACLK = 32768 kHz and a divide-by-8. */


#define EXIT_STATE sc_end                               /*!< State machine exit state. */
#define ENTRY_STATE sc_init                             /*!< State machine entry state. */

/*!
 * @brief Enable writes to program FRAM.
 *
 * Some variables are stored in program FRAM. RAM cannot be used because state is lost in deep sleep mode (LPM3.5).
 * The Program FRAM Write Protect bit must be cleared (and interrupts disabled) before a write.
 */
void fram_write_enable() {
    __disable_interrupt();      // TI advise against having interrupts enabled during a write of Program FRAM.
    SYSCFG0 = FRWPPW | DFWP;    // Clear the PFWP bit (program FRAM write protect). Leave the DFWP bit set (user FRAM).
}

/*!
 * @brief Disable writes to program FRAM.
 *
 * Sets the Program FRAM Write Protect bit and re-enables interrupts.
 */
void fram_write_disable() {
    SYSCFG0 = FRWPPW | DFWP | PFWP;  // Set both program FRAM and user FRAM write protect bits.
    __enable_interrupt();            // Re-enable global interrupts after the FRAM write has completed.
}

volatile int timerFlag = 0;    /*!< Flag set by the Timer Interrupt Service Routine. */
volatile int hdcFlag = 0;      /*!< Flag set by the HDC2021 humidity sensor data-ready Interrupt Service Routine. */


#pragma PERSISTENT(minutecounter)
int minutecounter = 0;         /*!< Incremented each time the sampling loop is run. */

/** Hard-coded NDEF message containing one text record
 *  "Programming Mode. Connect to serial port at 9600 baud." */
const char ndefmsg_progmode[] = {0x03, 0x3D, 0xD1, 0x01,
                                 0x39, 0x54, 0x02, 0x65,
                                 0x6E, 0x50, 0x72, 0x6F,
                                 0x67, 0x72, 0x61, 0x6D,
                                 0x6D, 0x69, 0x6E, 0x67,
                                 0x20, 0x4D, 0x6F, 0x64,
                                 0x65, 0x2E, 0x20, 0x43,
                                 0x6F, 0x6E, 0x6E, 0x65,
                                 0x63, 0x74, 0x20, 0x74,
                                 0x6F, 0x20, 0x73, 0x65,
                                 0x72, 0x69, 0x61, 0x6C,
                                 0x20, 0x70, 0x6F, 0x72,
                                 0x74, 0x20, 0x61, 0x74,
                                 0x20, 0x39, 0x36, 0x30,
                                 0x30, 0x20, 0x62, 0x61,
                                 0x75, 0x64, 0x2E, 0xFE};

/** Hard-coded NDEF message containing one text record
 *  "Config check failed. See cuplTag docs." */
const char ndefmsg_noconfig[] = {0x03, 0x2D, 0xD1, 0x01,
                                 0x29, 0x54, 0x02, 0x65,
                                 0x6E, 0x43, 0x6F, 0x6E,
                                 0x66, 0x69, 0x67, 0x20,
                                 0x63, 0x68, 0x65, 0x63,
                                 0x6B, 0x20, 0x66, 0x61,
                                 0x69, 0x6C, 0x65, 0x64,
                                 0x2E, 0x20, 0x53, 0x65,
                                 0x65, 0x20, 0x63, 0x75,
                                 0x70, 0x6C, 0x54, 0x61,
                                 0x67, 0x20, 0x64, 0x6F,
                                 0x63, 0x73, 0x2E, 0xFE};

/** Hard-coded NDEF message containing one text record
 *  "Error: Invalid state transition." */
const char ndefmsg_badtrns[] =  {0x03, 0x27, 0xD1, 0x01,
                                 0x23, 0x54, 0x02, 0x65,
                                 0x6E, 0x45, 0x72, 0x72,
                                 0x6F, 0x72, 0x3A, 0x20,
                                 0x49, 0x6E, 0x76, 0x61,
                                 0x6C, 0x69, 0x64, 0x20,
                                 0x73, 0x74, 0x61, 0x74,
                                 0x65, 0x20, 0x74, 0x72,
                                 0x61, 0x6E, 0x73, 0x69,
                                 0x74, 0x69, 0x6F, 0x6E,
                                 0x2E, 0xFE};

/** States in the Finite State Machine are represented by a code.
 *  This is used each time the state machine is run, to determine:
 *
 *  1. Which state function to call in main().
 *  2. The next state in lookup_transitions().  */
typedef enum state_codes {
    sc_init,                    /*!< State code for init_state() */
    sc_init_reqmemon,           /*!< State code for init_reqmemon() */
    sc_init_waitmemon,          /*!< State code for init_waitmemon() */
    sc_init_ntag,               /*!< State code for init_ntag() */
    sc_init_progmode,           /*!< State code for init_progmode() */
    sc_init_configcheck,        /*!< State code for init_configcheck() */
    sc_init_errorcheck,         /*!< State code for init_errorcheck() */
    sc_init_wakeupcheck,        /*!< State code for init_wakeupcheck() */
    sc_init_batvwait,           /*!< State code for init_batvwait() */
    sc_init_rtc_slow,           /*!< State code for init_rtc_slow() */
    sc_init_rtc_1min,           /*!< State code for init_rtc_1min() */
    sc_smpl_checkcounter,       /*!< State code for smpl_checkcounter() */
    sc_smpl_hdcreq,             /*!< State code for smpl_hdcreq() */
    sc_smpl_hdcwait,            /*!< State code for smpl_hdcwait() */
    sc_smpl_hdcread,            /*!< State code for smpl_hdcread() */
    sc_smpl_wait,               /*!< State code for smpl_wait() */
    sc_err_msg,                 /*!< State code for err_msg() */
    sc_end                      /*!< State code for end_state() */
} tstate;

/** Each state function returns at least one code from the list below.
 *  This is used by lookup_transitions() to determine the next state. */
typedef enum ret_codes { 
    tr_ok,
    tr_prog,
    tr_newconfig,
    tr_hdcreq,         /*!< Request a sample from the HDC2021 sensor. */
    tr_updatemin,
    tr_deepsleep,      /*!< cuplTag should enter a deep sleep state LPM3.5 */
    tr_lowbat,
    tr_fail,
    tr_samplingloop,   /*!< cuplTag is in the sampling loop. The reset was caused by an exit from LPM3.5 */
    tr_por,            /*!< cuplTag is NOT in the sampling loop. A Power-On-Reset has occurred. */
    tr_wait            /*!< cuplTag should enter a sleep state, such as LPM0, to wait for an event. */
} tretcode;

/** Events occur asynchronously to execution of the FSM. The MSP430 will typically wait for an event in sleep mode to save power.
 *  An example is an edge on the INT (interrupt) output from a temperature sensor. This is connected to an input on the MSP430,
 *  which is configured to call an Interrupt Service Routine (ISR). The ISR sets a flag and 'wakes up' the MSP430 from sleep mode.
 *
 *  The main() function is entered, flags are checked then cleared and the event variable is set according to the list of codes below.
 *  Finally, the state function is called with the event passed as an argument.
 *
 *  Multiple events can occur simultaneously, but only one at-a-time is passed to the FSM.
 *  */
typedef enum event_codes {
    evt_none,               /*!< No event has occurred. */
    evt_timerfinished,      /*!< The timer peripheral has counted down to 0. */
    evt_hdcint              /*!< Pin change interrupt received from the HDC2021 temperature and humidity sensor. */
} tevent;

// https://stackoverflow.com/questions/1371460/state-machines-tutorials
tretcode init_state(tevent);
tretcode init_reqmemon(tevent);
tretcode init_waitmemon(tevent);
tretcode init_ntag(tevent);
tretcode init_progmode(tevent);
tretcode init_configcheck(tevent);
tretcode init_errorcheck(tevent);
tretcode init_wakeupcheck(tevent);
tretcode init_batvwait(tevent);
tretcode init_rtc_slow(tevent);
tretcode init_rtc_1min(tevent);
tretcode smpl_checkcounter(tevent);
tretcode smpl_hdcreq(tevent);
tretcode smpl_hdcwait(tevent);
tretcode smpl_hdcread(tevent);
tretcode smpl_wait(tevent);
tretcode err_msg(tevent);
tretcode end_state(tevent);

/* This array must be in sync with the ::state_codes enumerator above.  */
tretcode (* state_fcns[])(tevent) = {
                          init_state,
                          init_reqmemon,
                          init_waitmemon,
                          init_ntag,
                          init_progmode,
                          init_configcheck,
                          init_errorcheck,
                          init_wakeupcheck,
                          init_batvwait,
                          init_rtc_slow,
                          init_rtc_1min,
                          smpl_checkcounter,
                          smpl_hdcreq,
                          smpl_hdcwait,
                          smpl_hdcread,
                          smpl_wait,
                          err_msg,
                          end_state
};


struct transition {
    tstate      src_state; /*!< Source state. */
    tretcode    ret_code;  /*!< Code returned after executing a state function. */
    tstate      dst_state; /*!< Destination state. */
};

/** The state transition table. */
struct transition state_transitions[] = {
                                         {sc_init,          tr_ok,      sc_init_reqmemon},

                                         {sc_init_reqmemon, tr_ok,      sc_init_waitmemon},

                                         {sc_init_waitmemon, tr_ok,      sc_init_ntag},
                                         {sc_init_waitmemon, tr_wait,    sc_init_waitmemon},

                                         {sc_init_ntag,    tr_ok,        sc_init_wakeupcheck},
                                         {sc_init_ntag,    tr_newconfig, sc_init_rtc_slow},
                                         {sc_init_ntag,    tr_prog,      sc_init_progmode},

                                         {sc_init_progmode,  tr_ok,      sc_init_progmode},
                                         {sc_init_progmode,  tr_wait,    sc_init_progmode},
                                         {sc_init_progmode,  tr_fail,    sc_err_msg},

                                         {sc_init_wakeupcheck,  tr_por,           sc_init_rtc_slow},
                                         {sc_init_wakeupcheck,  tr_samplingloop,  sc_smpl_checkcounter},

                                         {sc_init_rtc_slow,  tr_ok,     sc_init_batvwait},

                                         {sc_init_batvwait,  tr_ok,     sc_init_configcheck},
                                         {sc_init_batvwait,  tr_wait,   sc_init_batvwait},

                                         {sc_init_configcheck,  tr_ok,          sc_init_errorcheck},
                                         {sc_init_configcheck,  tr_deepsleep,   sc_end},

                                         {sc_init_errorcheck,  tr_ok,           sc_init_rtc_1min},
                                         {sc_init_errorcheck,  tr_deepsleep,    sc_end},

                                         {sc_init_rtc_1min,    tr_ok,      sc_smpl_checkcounter},

                                         {sc_smpl_checkcounter, tr_hdcreq,      sc_smpl_hdcreq},
                                         {sc_smpl_checkcounter, tr_updatemin,   sc_smpl_wait},

                                         {sc_smpl_hdcreq,   tr_ok,      sc_smpl_hdcwait},

                                         {sc_smpl_hdcwait,  tr_ok,      sc_smpl_hdcread},
                                         {sc_smpl_hdcwait,  tr_wait,    sc_smpl_hdcwait},

                                         {sc_smpl_hdcread,  tr_ok,      sc_smpl_wait},
                                         {sc_smpl_hdcread,  tr_lowbat,  sc_end},

                                         {sc_smpl_wait,     tr_deepsleep,   sc_end},

                                         {sc_err_msg,  tr_deepsleep,     sc_end}
                                         
};


/*!
 *   @brief Look up the next state in the Finite State Machine.
 *
 *   The look-up is performed by iterating through an array of transitions.
 *   An error state is returned if no match is found.
 *
 *   @param[in] curstate Current state.
 *   @param[in] rc Code returned from the current state.
 *   @return Next state.
 */
tstate lookup_transitions(tstate curstate, tretcode rc)
{
    tstate nextstate = sc_err_msg; /* This should never be reached. */
    int i=0;

    /* Read each transition in the state_transitions array. */
    for (i=0; i<sizeof(state_transitions)/sizeof(state_transitions[0]); i++)
    {
        /* If a transition that matches the current state and return code is found... */
        if ((state_transitions[i].src_state == curstate) && (state_transitions[i].ret_code == rc))
        {
            /* ...use it to set the next state and break out of the loop. */
            nextstate = state_transitions[i].dst_state;
            break;
        }
    }

    return nextstate;
}

/*!
 *   @brief Write an NDEF message to the NFC EEPROM.
 *
 *   The NDEF message normally contains one text record. It can be created with an
 *   external program and stored as a constant array. The function is used to display simple
 *   error messages to the end-user.
 *
 *   @param[in] msgptr Pointer an NDEF message array.
 *   @param[in] len Length of the NDEF message.
 */
static void writetxt(const char * msgptr, int len) {
    int eepindex = 0;
    int blk;

    eep_cp(&eepindex, msgptr, len);
    for (blk=0; blk<4; blk++) {
        eep_write(blk, blk);
    }
    eep_waitwritedone();
}

/*!
 *   @brief Kick the watchdog, to prevent it from timing out.
 *
 *   This is done by writing to the watchdog control register.
 */
static void wdog_kick()
{
    /*
     * WDTPW = Watchdog password.
     * WDTSSEL__ACLK = Use the 32.768 kHZ auxiliary clock (ACLK) as a source for the watchdog timer.
     * WDTCNTCL = Clear the watchdog timer.
     * WDTIS = Watchdog timer interval select. 8192K corresponds to 4 minutes, 16 seconds at 32 kHz.
     */
    WDTCTL = WDTPW | WDTSSEL__ACLK | WDTCNTCL | WDTIS__8192K;
}

/*!
 *  @brief Start a single-shot timer.
 *
 *  An interrupt fires when the timer has finished counting. The MSP430 
 *  can sleep in LPM3 whilst waiting for it. This saves power over delay loops.
 *
 *  The function is best suited to pausing execution for a short time (milliseconds).
 *
 *  @param[in] intervalCycles Number of 4.096 kHz clock cycles to count.
 *
 */
static void start_timer(unsigned int intervalCycles)
{
    /* Initialise a continuous mode parameters struct. */
    Timer_B_initContinuousModeParam initContParam = {0};
    
    /* Set the clock source to ACLK / 8 = 32.768kHz / 8. */
    initContParam.clockSource = TIMER_B_CLOCKSOURCE_ACLK;
    initContParam.clockSourceDivider = TIMER_B_CLOCKSOURCE_DIVIDER_8;

    /* Disable TBIFG by de-asserting TBIE.
     * Timer_B has 2 dedicated interrupt request outputs. Only the latter is used.:
     * TBIFG: Multiplexed interrupt flag.
     * CCIFG: Dedicated interrupt flag for Capture Compare Register 0.  */
    initContParam.timerInterruptEnable_TBIE = TIMER_B_TBIE_INTERRUPT_DISABLE;

    /* Clear the count value and disable the timer. */
    initContParam.timerClear = TIMER_B_DO_CLEAR;
    initContParam.startTimer = false;

    /* Write all settings from the parameters struct to Timer_B1. */
    Timer_B_initContinuousMode(TB1_BASE, &initContParam);

    /* Clear any existing Capture Compare Register interrupts. */
    Timer_B_clearCaptureCompareInterrupt(TB1_BASE, TIMER_B_CAPTURECOMPARE_REGISTER_0);

    /* Initialise a compare mode parameters struct. */
    Timer_B_initCompareModeParam initCompParam = {0};

    /* Set the compare register to CCR0. */
    initCompParam.compareRegister = TIMER_B_CAPTURECOMPARE_REGISTER_0;

    /* Enable interrupt CCIFG. This fires when the counter equals the compare value in CCR0. */
    initCompParam.compareInterruptEnable = TIMER_B_CAPTURECOMPARE_INTERRUPT_ENABLE;
    
    /* Set the timer output to the interrupt flag value. 
     * This can be routed to an output pin, but it is not used. */
    initCompParam.compareOutputMode = TIMER_B_OUTPUTMODE_OUTBITVALUE;

    /* Set the compare value to intervalCycles. */
    initCompParam.compareValue = intervalCycles;

    /* Write all settings from the compare mode structure to Timer_B1. */
    Timer_B_initCompareMode(TB1_BASE, &initCompParam);

    /* Start the counter from 0. */
    Timer_B_startCounter(TB1_BASE, TIMER_B_CONTINUOUS_MODE);
}

/*!
 *  @brief Power down the VMEM domain.
 *
 *   The load switch enable pin is set low, breaking the circuit between VDD and VMEM.
 *   This is done to save power in sleep mode. The NT3H2111 EEPROM will otherwise draw ~10uA.
 */
static void memoff()
{
    // Set the load switch enable pin P3.2 LOW.
    GPIO_setOutputLowOnPin(
            GPIO_PORT_P3,
            GPIO_PIN2
    );

    // Stop the timer if it is running. Use the RTC for delays when VMEM=0V.
    Timer_B_stop(TB1_BASE);

    // All I2C slaves are powered down so disable the MSP430 peripheral to save power.
    i2c_off();
}
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
void main(void)
{
    volatile int error;
    tstate cur_state = ENTRY_STATE;
    tretcode rc;
    tretcode (* state_fun)(tevent);
    tevent evt;


    while (1) {
        // Process events
        if (timerFlag)
        {
            timerFlag = 0;
            evt = evt_timerfinished;
        }
        else if (hdcFlag)
        {
            hdcFlag = 0;
            evt = evt_hdcint;
        }
        else
        {
            evt = evt_none;
        }

        state_fun = state_fcns[cur_state];
        rc = state_fun(evt);
        if (rc == tr_wait)
        {
            // Sleep in LPM3 whilst waiting for the timer or the HDC2010 to assert it's interrupt output.
            __bis_SR_register(LPM3_bits + GIE);
        }
        cur_state = lookup_transitions(cur_state, rc);
    }
}

//******************************************************************************
//
//This is the TIMER1_A3 interrupt vector service routine.
//
//******************************************************************************
#if defined(__TI_COMPILER_VERSION__) || defined(__IAR_SYSTEMS_ICC__)
#pragma vector=TIMER1_B0_VECTOR
__interrupt
#elif defined(__GNUC__)
__attribute__((interrupt(TIMER1_A0_VECTOR)))
#endif
void TIMER1_B0_ISR(void)
{
    Timer_B_stop(TB1_BASE);
    Timer_B_disableInterrupt(TB1_BASE);
    timerFlag = 1;
    __bic_SR_register_on_exit(LPM3_bits); // Clear LPM bits upon ISR Exit
}


//******************************************************************************
//
//This is the PORT_2 interrupt vector service routine.
//
//******************************************************************************
#if defined(__TI_COMPILER_VERSION__) || defined(__IAR_SYSTEMS_ICC__)
#pragma vector=PORT1_VECTOR
__interrupt void Port_1(void)
#elif defined(__GNUC__)
void __attribute__ ((interrupt(PORT2_VECTOR))) Port_2 (void)
#else
#error Compiler not supported!
#endif
{
  P1IFG &= ~BIT1;                           // P4.3 IFG cleared
  if ((P1IN & BIT1) == 0)
  {
      // P1.1 is low.
      hdcFlag = 1;
      __bic_SR_register_on_exit(LPM3_bits);     // Clear LPM bits upon ISR Exit
  }
}

#if defined(__TI_COMPILER_VERSION__) || defined(__IAR_SYSTEMS_ICC__)
#pragma vector = RTC_VECTOR
__interrupt void RTC_ISR(void)
#elif defined(__GNUC__)
void __attribute__ ((interrupt(RTC_VECTOR))) RTC_ISR (void)
#else
#error Compiler not supported!
#endif
{
    switch(__even_in_range(RTCIV, RTCIV_RTCIF))
    {
        case RTCIV_NONE : break;            // No interrupt pending
        case RTCIV_RTCIF:                   // RTC Overflow
            break;
        default:          break;
    }
}

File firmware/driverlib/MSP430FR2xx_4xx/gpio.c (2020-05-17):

/* --COPYRIGHT--,BSD
 * Copyright (c) 2017, Texas Instruments Incorporated
 * All rights reserved.
 *
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
 * *  Redistributions of source code must retain the above copyright
 *    notice, this list of conditions and the following disclaimer.
 *
 * *  Redistributions in binary form must reproduce the above copyright
 *    notice, this list of conditions and the following disclaimer in the
 *    documentation and/or other materials provided with the distribution.
 *
 * *  Neither the name of Texas Instruments Incorporated nor the names of
 *    its contributors may be used to endorse or promote products derived
 *    from this software without specific prior written permission.
 *
 * THIS SOFTWARE IS PROVIDED BY THE COPYRIGHT HOLDERS AND CONTRIBUTORS "AS IS"
 * AND ANY EXPRESS OR IMPLIED WARRANTIES, INCLUDING, BUT NOT LIMITED TO,
 * THE IMPLIED WARRANTIES OF MERCHANTABILITY AND FITNESS FOR A PARTICULAR
 * PURPOSE ARE DISCLAIMED. IN NO EVENT SHALL THE COPYRIGHT OWNER OR
 * CONTRIBUTORS BE LIABLE FOR ANY DIRECT, INDIRECT, INCIDENTAL, SPECIAL,
 * EXEMPLARY, OR CONSEQUENTIAL DAMAGES (INCLUDING, BUT NOT LIMITED TO,
 * PROCUREMENT OF SUBSTITUTE GOODS OR SERVICES; LOSS OF USE, DATA, OR PROFITS;
 * OR BUSINESS INTERRUPTION) HOWEVER CAUSED AND ON ANY THEORY OF LIABILITY,
 * WHETHER IN CONTRACT, STRICT LIABILITY, OR TORT (INCLUDING NEGLIGENCE OR
 * OTHERWISE) ARISING IN ANY WAY OUT OF THE USE OF THIS SOFTWARE,
 * EVEN IF ADVISED OF THE POSSIBILITY OF SUCH DAMAGE.
 * --/COPYRIGHT--*/
//*****************************************************************************
//
// gpio.c - Driver for the gpio Module.
//
//*****************************************************************************

//*****************************************************************************
//
//! \addtogroup gpio_api gpio
//! @{
//
//*****************************************************************************

#include "inc/hw_memmap.h"

#if defined(__MSP430_HAS_PORT1_R__) || defined(__MSP430_HAS_PORT2_R__) ||\
    defined(__MSP430_HAS_PORTA_R__)
#include "gpio.h"

#include <assert.h>

static const uint16_t GPIO_PORT_TO_BASE[] = {
    0x00,
#if defined(__MSP430_HAS_PORT1_R__)
    __MSP430_BASEADDRESS_PORT1_R__,
#elif defined(__MSP430_HAS_PORT1__)
    __MSP430_BASEADDRESS_PORT1__,
#else
    0xFFFF,
#endif
#if defined(__MSP430_HAS_PORT2_R__)
    __MSP430_BASEADDRESS_PORT2_R__,
#elif defined(__MSP430_HAS_PORT2__)
    __MSP430_BASEADDRESS_PORT2__,
#else
    0xFFFF,
#endif
#if defined(__MSP430_HAS_PORT3_R__)
    __MSP430_BASEADDRESS_PORT3_R__,
#elif defined(__MSP430_HAS_PORT3__)
    __MSP430_BASEADDRESS_PORT3__,
#else
    0xFFFF,
#endif
#if defined(__MSP430_HAS_PORT4_R__)
    __MSP430_BASEADDRESS_PORT4_R__,
#elif defined(__MSP430_HAS_PORT4__)
    __MSP430_BASEADDRESS_PORT4__,
#else
    0xFFFF,
#endif
#if defined(__MSP430_HAS_PORT5_R__)
    __MSP430_BASEADDRESS_PORT5_R__,
#elif defined(__MSP430_HAS_PORT5__)
    __MSP430_BASEADDRESS_PORT5__,
#else
    0xFFFF,
#endif
#if defined(__MSP430_HAS_PORT6_R__)
    __MSP430_BASEADDRESS_PORT6_R__,
#elif defined(__MSP430_HAS_PORT6__)
    __MSP430_BASEADDRESS_PORT6__,
#else
    0xFFFF,
#endif
#if defined(__MSP430_HAS_PORT7_R__)
    __MSP430_BASEADDRESS_PORT7_R__,
#elif defined(__MSP430_HAS_PORT7__)
    __MSP430_BASEADDRESS_PORT7__,
#else
    0xFFFF,
#endif
#if defined(__MSP430_HAS_PORT8_R__)
    __MSP430_BASEADDRESS_PORT8_R__,
#elif defined(__MSP430_HAS_PORT8__)
    __MSP430_BASEADDRESS_PORT8__,
#else
    0xFFFF,
#endif
#if defined(__MSP430_HAS_PORT9_R__)
    __MSP430_BASEADDRESS_PORT9_R__,
#elif defined(__MSP430_HAS_PORT9__)
    __MSP430_BASEADDRESS_PORT9__,
#else
    0xFFFF,
#endif
#if defined(__MSP430_HAS_PORT10_R__)
    __MSP430_BASEADDRESS_PORT10_R__,
#elif defined(__MSP430_HAS_PORT10__)
    __MSP430_BASEADDRESS_PORT10__,
#else
    0xFFFF,
#endif
#if defined(__MSP430_HAS_PORT11_R__)
    __MSP430_BASEADDRESS_PORT11_R__,
#elif defined(__MSP430_HAS_PORT11__)
    __MSP430_BASEADDRESS_PORT11__,
#else
    0xFFFF,
#endif
    0xFFFF,
#if defined(__MSP430_HAS_PORTJ_R__)
    __MSP430_BASEADDRESS_PORTJ_R__
#elif defined(__MSP430_HAS_PORTJ__)
    __MSP430_BASEADDRESS_PORTJ__
#else
    0xFFFF
#endif
};

void GPIO_setAsOutputPin(uint8_t selectedPort, uint16_t selectedPins) {

    uint16_t baseAddress = GPIO_PORT_TO_BASE[selectedPort];

    #ifndef NDEBUG
    if(baseAddress == 0xFFFF) {
        return;
    }
    #endif

    // Shift by 8 if port is even (upper 8-bits)
    if((selectedPort & 1) ^ 1) {
        selectedPins <<= 8;
    }

#ifdef __MSP430_HAS_PASEL0__
    HWREG16(baseAddress + OFS_PASEL0) &= ~selectedPins;
#endif
#ifdef __MSP430_HAS_PASEL1__
    HWREG16(baseAddress + OFS_PASEL1) &= ~selectedPins;
#endif
    HWREG16(baseAddress + OFS_PADIR) |= selectedPins;

    return;
}
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

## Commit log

2020-07-07 Removed field detect. Added progmode pin check to uart.
2020-07-15 Fixed bug with MEM not turning on.
    [comms_uart.c, main.c]
2020-07-20 Ensuring that UART does not cause sleep whilst nPRG is asserted.
    This keeps the tag responsive in programming mode.
2020-07-21 Improved state machines and added error messages.
    No more while(1) loops. NDEF text records added to the top of main.c
    [comms_uart.c, main.c]
2020-08-08 Altered version string and added voltage check.
2020-12-16 Added i2c_off and updated docs for HT05
2021-01-19 Added nt3h.c and batv.c from cuplcodec 2.0.9
    Also added a scan for an NT3H when its I2C device has been inadvertently changed. Added <x: > around the version string.
2021-02-07 Reduced current consumption by using LPM3.5
    Sleep current measured as 420nA in LPM3.5, which is down from 1.5uA in LPM3 used previously. Many variables have been moved to FRAM, using the PERSISTENT pragma and the intiailisation of these have had to change. BKMEM is used to store a variable that indicates whether or not initialisation can be skipped or not.
    [comms_uart.c, main.c, nt3h.c]
2021-04-19 Frequency of external oscillator measured as 32.7685 kHz
    [main.c]
2021-04-19 Moved HT07rev2 from the private repo.
    Also removed debug features from main.c (for testing 32.768 kHz XTAL frequency).
    [HT07-B_Cu.gbr, HT07-B_Mask.gbr, HT07-B_Paste.gbr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]
2021-04-21 HT07R2 sent to manufacture at Eurocircuits
    [HT07-B_Cu.gbr, HT07-B_Mask.gbr, HT07-B_Paste.gbr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]
2021-04-24 Added turbo mode
    In turbo mode, temperature and humidity are sampled at 1Hz. Also added a 3 second delay at startup, before measuring the battery voltage. Finally nt3h_check_address has been modified to return 1 when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
2021-04-28 Fixed a bug in nt3h_update_cc
    In the event of an error, rxData can be read back as zero so it is important to set rxData[0] to the device each time, otherwise the device address can also change to zero.
    [i2c.c, main.c, nt3h.c]
2021-04-30 SVS does not cause a stall unless battery level is low.
    [main.c]
2021-05-04 Issued evaluation board for new HT07R2.
    [comms_uart.c, main.c]
2021-08-16 Clear the NT3H lock to I2C
    Also increased update time from 1s to 3s in turbo mode.
    [HT07-B_Cu.gbr, HT07-B_Mask.gbr, HT07-B_Paste.gbr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]
2021-08-29 Up-issued to Rev 3
    This changes the humidity sensor to HDC2022 from HDC2021. Also adds alternate parts for the MSP430 and NT3H to the schematic.
    [HT07.kicad_pcb, HT07.sch]
2021-09-27 Started to update documentation.
    [HT07.kicad_pcb, HT07.sch]
2021-09-29 Added configuration with UART part 2.
2021-09-29 Added gerbers
    [HT07-B_Cu.gbr, HT07-B_Mask.gbr, HT07-B_Paste.gbr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]
2022-01-04 Fixed excess current draw >0.5uA in LPM3.5 bug.
    Current varied based on temperature and hand placement etc. Much higher than the 0.5uA expected in LPM3.5. Pull up/down resistors were not explicitly defined for all pins. P3.5 (nPRG) was set as an input, with a weak pull-down, despite a 47K weak external pull-up.
    [comms_uart.c, main.c]
2022-08-23 Added doxygen comments to I2C driver
2022-08-26 Added battery voltage docs

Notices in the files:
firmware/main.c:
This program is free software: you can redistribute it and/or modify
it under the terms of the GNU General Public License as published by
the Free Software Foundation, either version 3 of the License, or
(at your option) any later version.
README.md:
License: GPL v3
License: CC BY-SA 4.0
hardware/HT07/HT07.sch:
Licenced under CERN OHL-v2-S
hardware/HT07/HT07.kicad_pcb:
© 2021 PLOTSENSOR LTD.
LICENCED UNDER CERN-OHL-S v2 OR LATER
